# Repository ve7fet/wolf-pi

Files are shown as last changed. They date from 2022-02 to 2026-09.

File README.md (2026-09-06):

# wolf-pi

## What is it?
A carrier board for the NanoPi Duo 2 supporting Direwolf and other amateur radio applications. 
See http://wiki.friendlyarm.com/wiki/index.php/NanoPi_Duo2 for details on the NanoPi Duo 2. Schematics of the NanoPi Duo 2 and it's 
factory carrier board schematic are in the [docs](./docs) folder.

The NanoPi Duo 2 has a built-in sound card (ADC/DAC), GPIO, WiFi, and Ethernet, making it an attractive product for integration.

This device allows you to use a NanoPi Duo 2 with the Direwolf Project. See https://packet-radio.net/direwolf/

## Implementation
In this application, we wire out the Ethernet (following the design used on the NanoPi IoT carrier board), as that is often preferred 
in a stand-alone application, for connection to a LAN.

The GPIO is used with the built-in functions in Direwolf for /PTT and software indication of Carrier Detect.

A 555-based (selectable) time-out-timer is employed, to prevent a locked-up transmitter or software from holding up the radio channel
with dead carrier. This circuit is based on the one recommended in the Direwolf documentation.

For telemetry applications, support for the ADS1115 ADC converter is included. This is accomplished by using a commonly available 
breakout board from Sparkfun/Adafruit/Universal Solder. The header pins for the breakout solder directly on to the carrier.

Non-populated resistor positions are provided for build-your-own voltage dividers for making single-ended ADC measurements (battery voltages, door switches, etc.).

JP2 is provided to facilitate easy measurement of the battery voltage on ADC AN0.

Support for Dallas 1-wire sensors is provided, with pads available to install a DS18B20 on-board, if desired. Note that the onboard DS18B20 will be measuring the temperature inside the enclosure...

ADC and 1-Wire are wired out to a header connector that is external to the case, for external connections.

The DB9 connector is wired to be compatible with Kantronics KPC3+ cables. Additional solder jumpers are provided to modify some of those pin functions for custom applications.

Additional GPIO (buffered) outputs are also added for future use.

Support for hardware COS (DCD) is provided for future applications.

Ferrite beads are used to reduce RFI/EMI.

The board is designed to be installed in a Hammond 1455K1201 case. Actually, it will fit the 1455J1201 (which is thinner). The -1202 version is less expensive (plastic end panels, vs aluminum ones), if you are going to be replacing the end panels with laser cut ones. End plates are still to be designed.

Alternatively, an enclosure has been designed in FreeCad, with the .stl [files available](./enclosure). Confirmed working for the v1.2 board, printed in PLA. Uses #4-40 hardware.

## Usage
The easiest way to get going is to install an [Armbian](https://armbian.com) image, using their imager.

As of 2026/09/03, it was installing:

*v26.11 rolling for NanoPi Duo2 running Armbian Linux 6.18.48-current-sunxi*

### Boot Configuration Changes
In order to utilize all the features of the implementation, additional configuration of the Armbian environment is required.

The following changes are needed to `/boot/armbianEnv.txt` in order to enable the sound card (codec), 1-wire, and i2c (for the ADS1115).

```
overlays=analog-codec i2c0 usbhost0 usbhost2 usbhost3 w1-gpio
param_w1_pin=PA13
param_w1_pin_int_pullup=0
```

### 1-Wire
With the changes to `/boot/armbianEnv.txt`, the 1-wire subsystem will be available in `/sys/bus/w1/devices`.

If the onboard sensor is installed, it should enumerate with a `28-` prefix.

Follow any of the many sources on the Internet for how to utilize it from there.

### ADC via i2c
With the changes to `/boot/armbianEnv.txt`, the ADS1115 daughter board should be detected. 

Install the i2c tools:

```
sudo apt install i2c-tools -y
```

Make sure the bus is there:

```
ve7fet@nanopiduo2:~$ ls /dev/i2c*
/dev/i2c-0
```

Make sure we can see the ADC at address 0x48:

```
ve7fet@nanopiduo2:~$ sudo i2cdetect -y 0
     0  1  2  3  4  5  6  7  8  9  a  b  c  d  e  f
00:                         -- -- -- -- -- -- -- --
10: -- -- -- -- -- -- -- -- -- -- -- -- -- -- -- --
20: -- -- -- -- -- -- -- -- -- -- -- -- -- -- -- --
30: -- -- -- -- -- -- -- -- -- -- -- -- -- -- -- --
40: -- -- -- -- -- -- -- -- 48 -- -- -- -- -- -- --
50: -- -- -- -- -- -- -- -- -- -- -- -- -- -- -- --
60: -- -- -- -- -- -- -- -- -- -- -- -- -- -- -- --
70: -- -- -- -- -- -- -- --
```

Unfortunately, the Armbian kernel doesn't have the driver compiled into it in order to use userspace tools. So, that means one will have to access it directly via i2c.

With a little massaging, the library from https://github.com/sanjuruk/ADS1X15_TLA2024_Linux is capable of accessing the ADC.

Note that the value returned by the "single ended" utility is the ADC count. In order to convert it back to a voltage, you'd need to do something like:

```
#include <cstdio>
#include <unistd.h>
#include "ADS1X15_TLA2024.h"

ADS1115 ads;  /* Use this for the 16-bit version */
// ADS1015 ads;     /* Use this for the 12-bit version */
// TLA2024 ads;

int DEBUG = 1;
float AIN0vout, AIN1vout, AIN2vout, AIN3vout;
float AIN0cal, AIN1cal, AIN2cal, AIN3cal;
float PGA = 4.096; /* PGA is defined by GAIN setting */

// AIN0 Resistors
float R5 = 10000; // 10k ohms
float R6 = 3000;  // 3k ohms
// AIN1 Resistors
float R7 = 1; // dummy, so we don't divide by 0
float R8 = 1; // dummy, so we don't divide by 0
// AIN2 Resistors
float R9 = 1000; // 1kohm
float R10 = 3740; // 3.74kohm
// AIN3 Resistors
float R12 = 1;
float R13 = 1;

// AIN0 Max Input Voltage
//
// VINmax = (VDD + 0.3) x ((R5 + R6)/R6)
// VINmax = (3.6) x ((13000)/3000)
// VINmax = 15.6VDC
//
// AIN2 Max Input Voltage
//
// VINmax = (VDD + 0.3) x ((R9 + R10)/R10)
// VINmax = (3.6) x ((4740)/3740)
// VINmax = 4.56VDC

int main()
{
    int16_t adc[4];
    int8_t i;

    if (DEBUG) {
        printf("Getting single-ended readings from AIN0..3\n");
        printf("ADC Range: +/- 4.096V (1 bit = 2mV/ADS1015, 0.125mV/ADS1115)\n");
        printf("ADC Max Input: VDD + 0.3 = 3.6VDC\n\n");
    }

  // The ADC input range (or gain) can be changed via the following
  // functions, but be careful never to exceed VDD +0.3V max, or to
  // exceed the upper and lower limits if you adjust the input range!
  // Setting these values incorrectly may destroy your ADC!
  //                                                                ADS1015  ADS1115
  //                                                                -------  -------
  // ads.setGain(GAIN_TWOTHIRDS);  // 2/3x gain +/- 6.144V  1 bit = 3mV      0.1875mV (default)
  //
  // We're using VDD = 3.3V, so we will use GAIN_ONE to get the most resolution, being
  // careful to choose our voltage divider resistors!
    ads.setGain(GAIN_ONE);        // 1x gain   +/- 4.096V  1 bit = 2mV      0.125mV
  // ads.setGain(GAIN_TWO);        // 2x gain   +/- 2.048V  1 bit = 1mV      0.0625mV
  // ads.setGain(GAIN_FOUR);       // 4x gain   +/- 1.024V  1 bit = 0.5mV    0.03125mV
  // ads.setGain(GAIN_EIGHT);      // 8x gain   +/- 0.512V  1 bit = 0.25mV   0.015625mV
  // ads.setGain(GAIN_SIXTEEN);    // 16x gain  +/- 0.256V  1 bit = 0.125mV  0.0078125mV

    for (i = 0; i < 4; i++) {
        adc[i] = ads.readADC_SingleEnded(i);
        if (DEBUG) {
            printf("AIN%i: %d\n", i, adc[i]);
        }
    }

    /* Calculate output voltage for AIN0. */
    AIN0vout = (adc[0]*(PGA/32767))*((R5+R6)/R6);
    printf("AIN0vout = %.2f\n", AIN0vout);

    /* Calculate output voltage for AIN1. */
    AIN1vout = (adc[1]*(PGA/32767))*((R7+R8)/R8);
    printf("AIN1vout = %.2f\n", AIN1vout);

    /* Calculate output voltage for AIN2. */
    AIN2vout = (adc[2]*(PGA/32767))*((R9+R10)/R10);
    printf("AIN2vout = %.2f\n", AIN2vout);

    /* Calculate output voltage for AIN3. */
    AIN3vout = (adc[3]*(PGA/32767))*((R12+R13)/R13);
    printf("AIN3vout = %.2f\n", AIN3vout);
```
See https://github.com/ve7fet/wolfpiADC for the full library.

### Sound Card
You can use `alsamixer` to set the audio levels. Use `sudo alsactl store` to save settings in `/var/lib/alsa/asound.state` (*remember to backup this file*).

If you run Direwolf out of the box, it will likely complain:

```
Audio input device 0 error code -5: Input/output error
```

That is because there is no capture device selected. You can either run this:

```
#mic1 CAPTURE switch (on/off) - this will let you use the microphone
/usr/bin/amixer -c 0 cset numid=18 on
```

Or, load `alsamixer`, and select MIC1 as the capture device.

### GPIO
We use GPIO for the /PTT (signal and LED), and the DCD LED.

Put the following in the `direwolf.conf` for Channel 0 to enable them:

```
MODEM 1200

# Our PTT is on GPIOL11 (Pin 9)
PTT GPIO 363
# Our DCD LED is on GPIOG11 (Pin 11)
DCD GPIO 203
```

Note that this is the deprecated sysfs way of using the GPIOs... but it works, for now.

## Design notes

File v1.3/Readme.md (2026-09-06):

This version makes the following changes from v1.2:

- Fix C14/C20 Silkscreen. 
- Change solder jumpers to open. YOU NEED TO SOLDER THE OPTIONS YOU WANT DURING ASSEMBLY.
- Change TOT jumper to solder type instead of pin header. 
- Change DB9 mounting holes to plated/GND. 
- Move ETH jack outward.
- Move C11, D3, JP6.
- Correct R11/C9/U1 connections for TOT
- Update value of R6 to increase Vmax for AIN0 from 13.2V to 15.6V

This version has NOT been manufactured (yet) to verify operation.

Project/Schematic/Board saved with KiCad V9.04. DRC needs to be re-run, errors/warnings addressed, 
and Gerbers re-exported (existing Gerbers have been removed, as they are no longer valid).

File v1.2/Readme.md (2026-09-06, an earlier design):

This is the initial prototype release.

Prototype boards WERE produced and tested with this release, and did work. 

Known issues:
- C11 obstructs the USB port on the NanoPi
- JP1 should have been a solder jumper, not a physical header
- C14/C20 silkscreens are swapped
- TOT doesn't function. R11 should connect from 3V3 to C9, and U1-6/7 
  should connect to junction of R11/C9 (field change required)
- AN0 max input with R5=10k/R6=3.74k is 13.2VDC. Change R6 to 3.00k 
  for 15.6VDC max.
- Radio MAY transmit for up to TOT value when device is powered on, due 
  to un-initialized GPIO pins

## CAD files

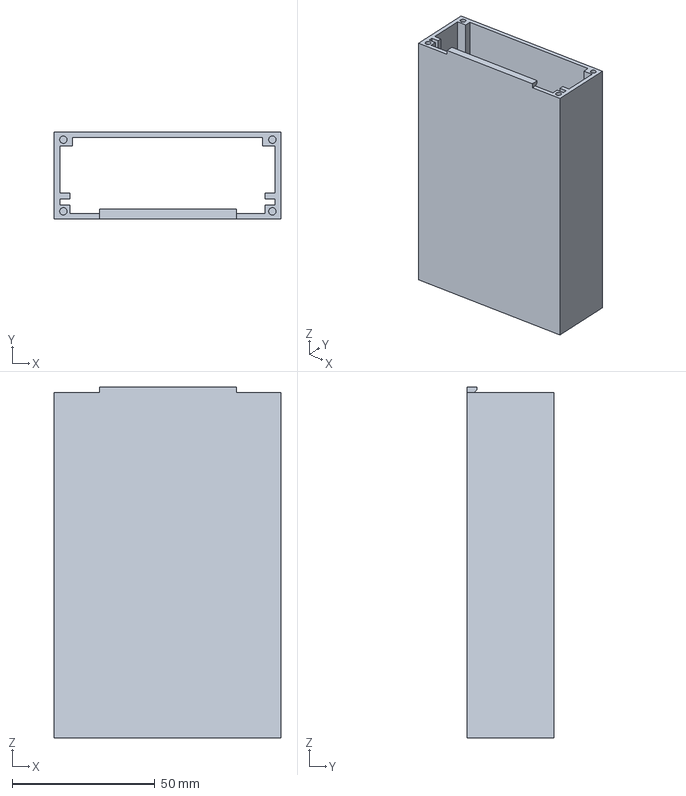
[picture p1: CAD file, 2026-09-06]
enclosure/WolfPiBox_v1.2_121mmdeep.FCStd
79.5 x 30.6 x 123.0 mm

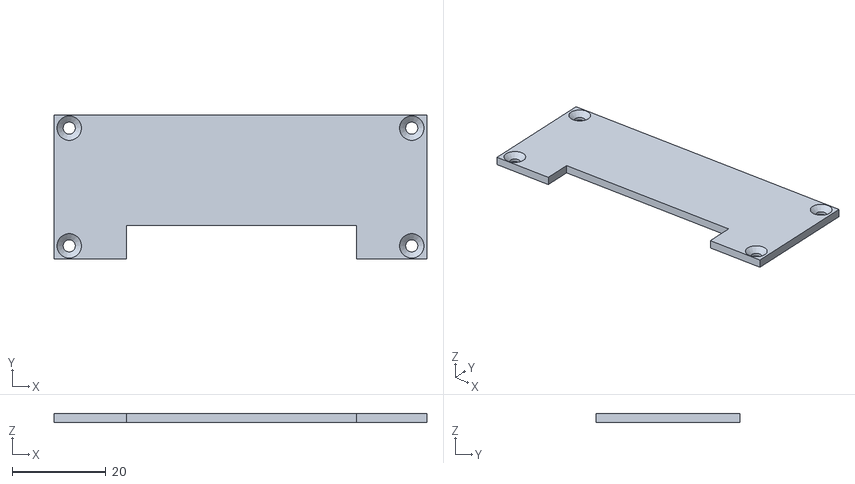
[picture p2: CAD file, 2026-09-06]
enclosure/WolfPiBox_v1.2_121mmdeep-TopLid.stl
79.5 x 30.6 x 2.00

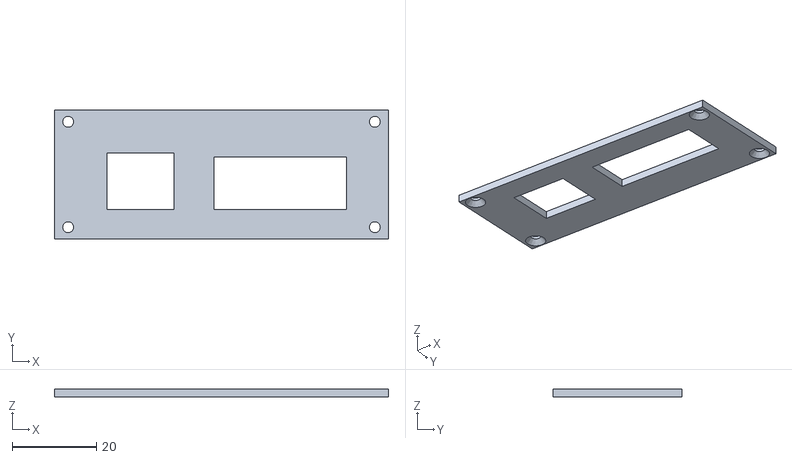
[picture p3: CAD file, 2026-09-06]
enclosure/WolfPiBox_v1.2_121mmdeep-BotLid.stl
79.5 x 30.6 x 2.00

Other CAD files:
enclosure/WolfPiBox_v1.2_121mmdeep-WolfPiCase.stl

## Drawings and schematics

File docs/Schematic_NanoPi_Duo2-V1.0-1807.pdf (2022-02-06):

D | D
C | C
B | B
A | A

# Revision: V1.0 1807 first release

# NanoPi Duo2

Size | Document Number | R e v
Date: | Sheet | o f

Title

NanoPi Duo2

A3

Thursday, September 27, 2018 | 1 | 11

V1.0 1807

Title

Thursday, September 27, 2018 | 1 | 11

Title

Thursday, September 27, 2018 | 1 | 11

D | D
C | C
B | B
A | A

## MicroUSB OTG

## IR-RX

AP6212

## USB3

# POWER

## LINE OUT

## MICIN1

## 2.54mm 16Pin

SD | TF CARD
USB0 | OSC 24M | 24MHz

## IR RX

## EPHY

H3

## MicroUSB

## WIFI

# BLOCK

DDR3 16X1 | DRAMC0

## UART0

## GPIO

I2C0

## SPI1

## 2.54mm 16Pin

SPI Flash | SPI0 | Bluetooth

BLOCK

Thursday, September 27, 2018 | 2 | 11

BLOCK

Thursday, September 27, 2018 | 2 | 11

BLOCK

Thursday, September 27, 2018 | 2 | 11

D | D
C | C
B | B
A | A
SY8089A | SYSTEM 1.2V/2A

# POWER TREE

MicroUSB/Ext-5V | 5V/2A

# VDD_5V_OUT

RT8059 | DRAM

# VCC-IO/RTC/VCC-WIFI/AVCC RT8059

MP2143DJ | VCC-CPUX

1.5V/1A

1.3V/3A

3.3V/1A

# VCC2.8V-CAM

# RT9011-FMPJ6

# VCC1.5V-CAM

RT9011-PGPJ6 | VCC3V-CAM

POWER TREE

Thursday, September 27, 2018 | 3 | 11

POWER TREE

Thursday, September 27, 2018 | 3 | 11

POWER TREE

Thursday, September 27, 2018 | 3 | 11

55

44

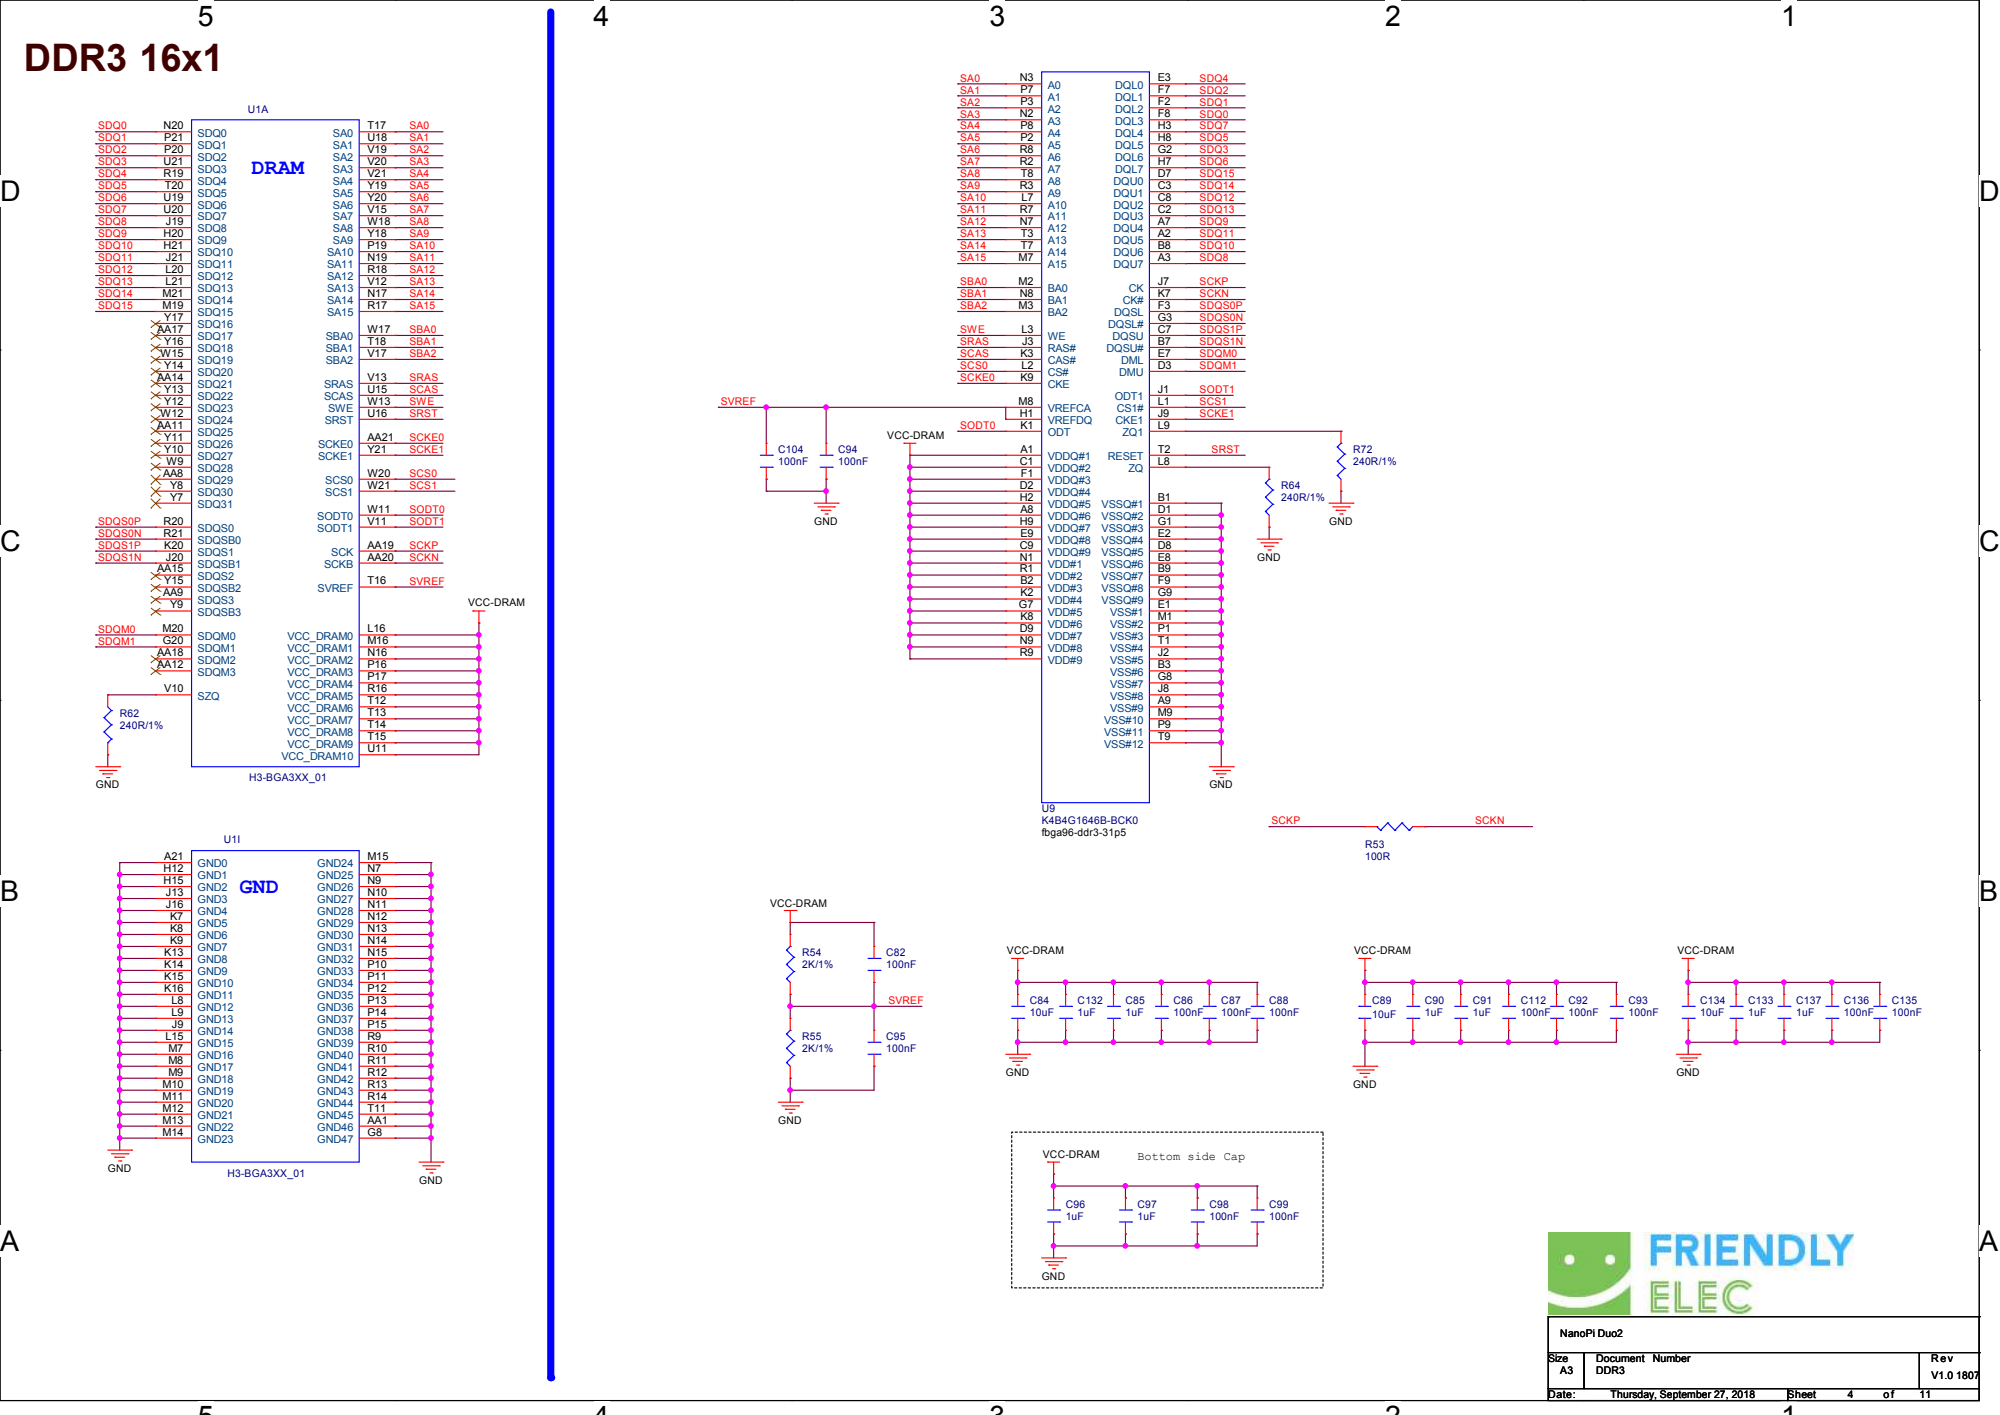
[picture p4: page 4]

D | D

# CPU 01

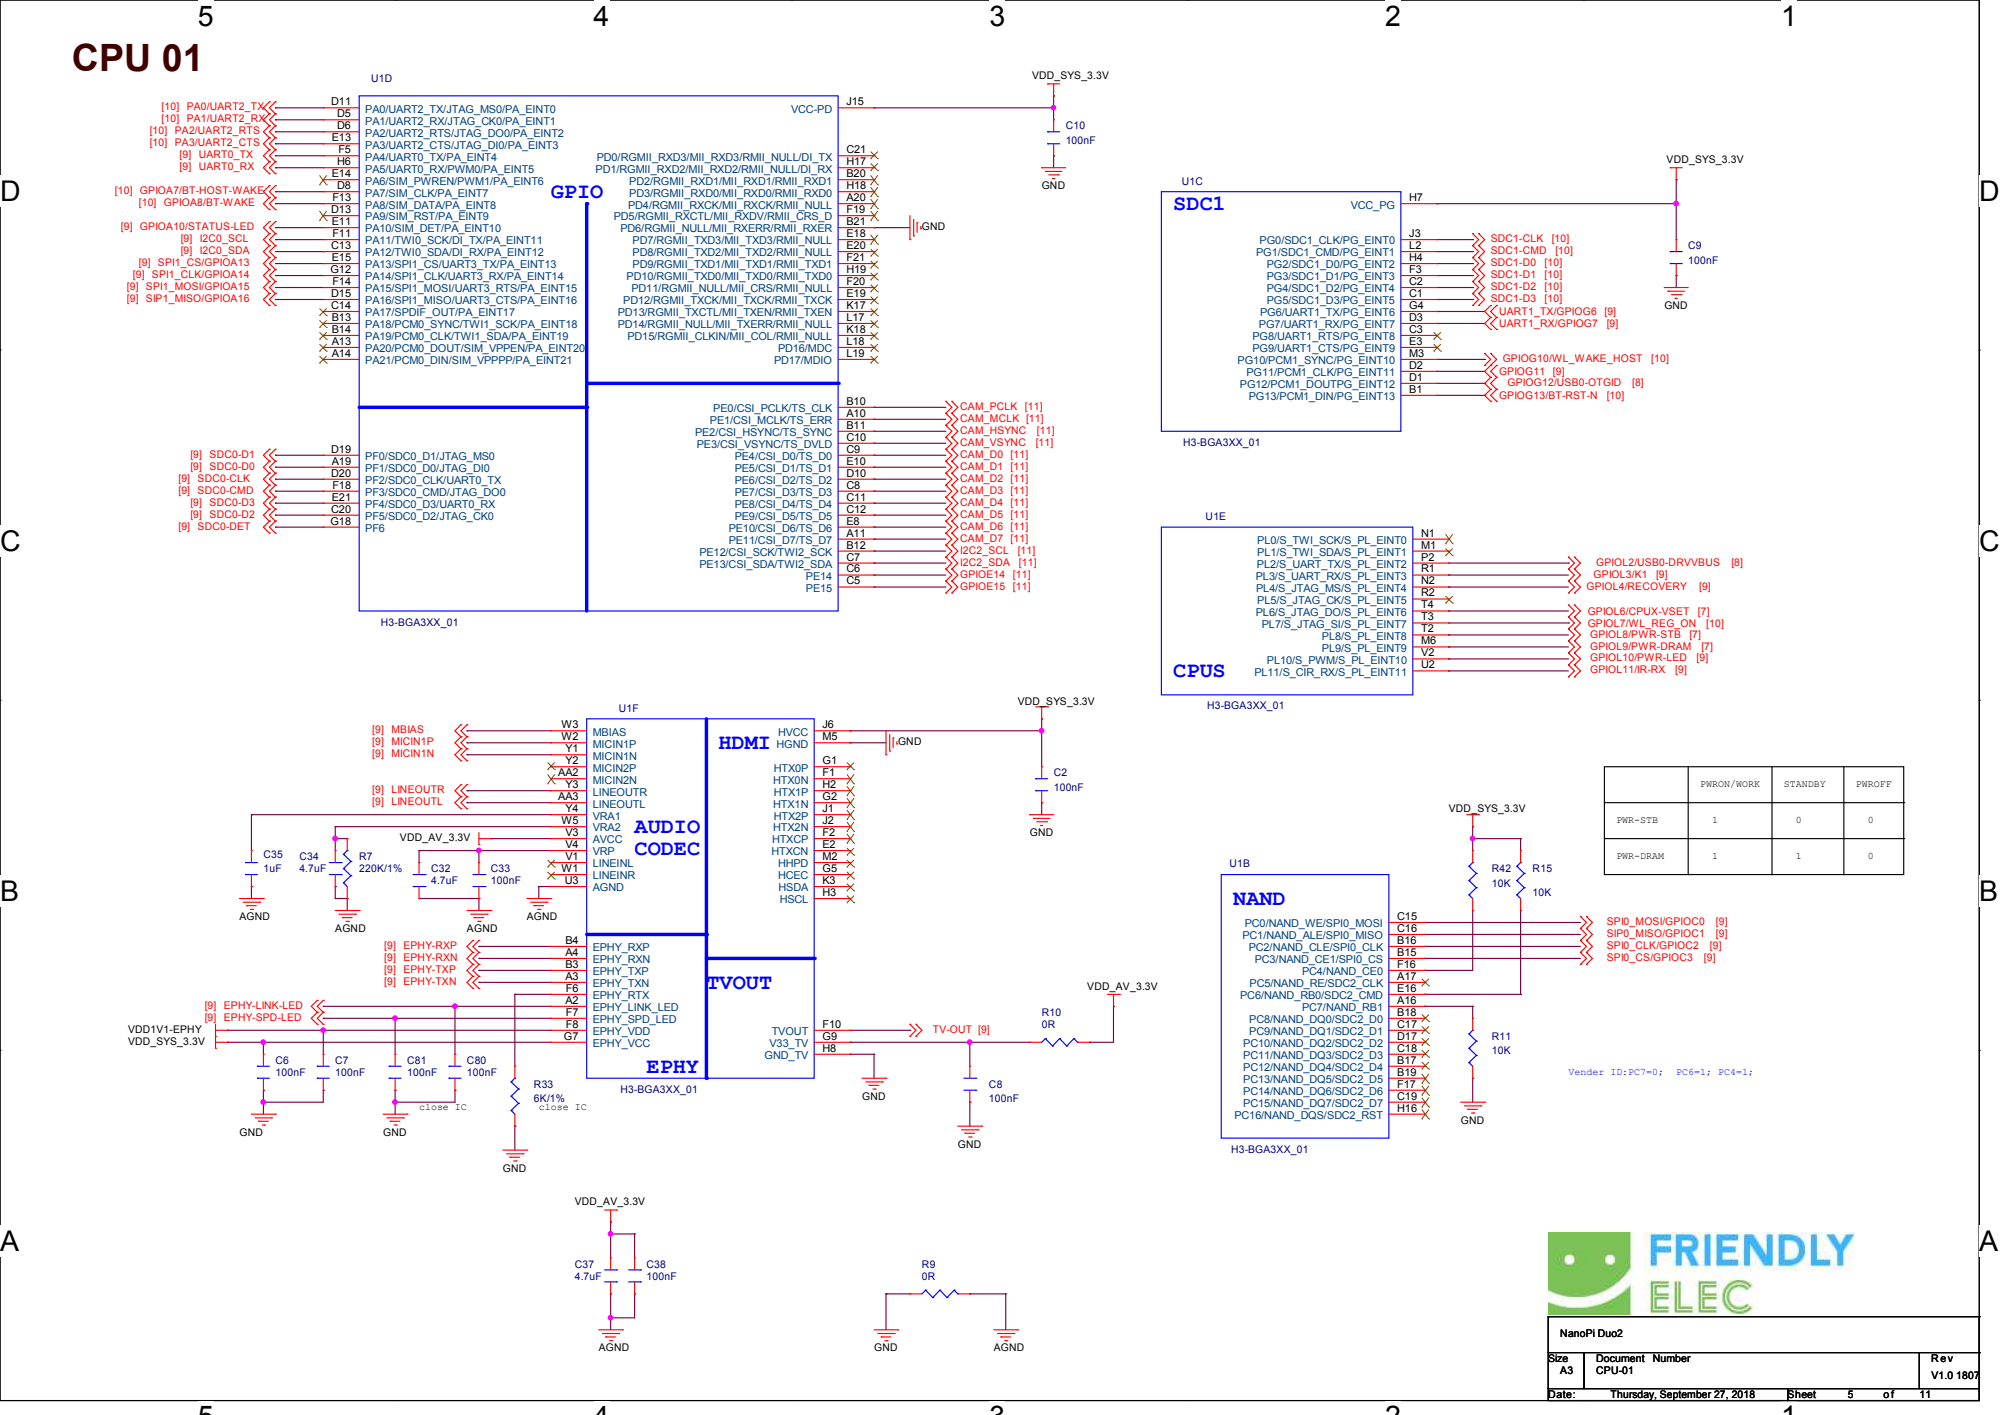
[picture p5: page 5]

D | D

# CPU 02

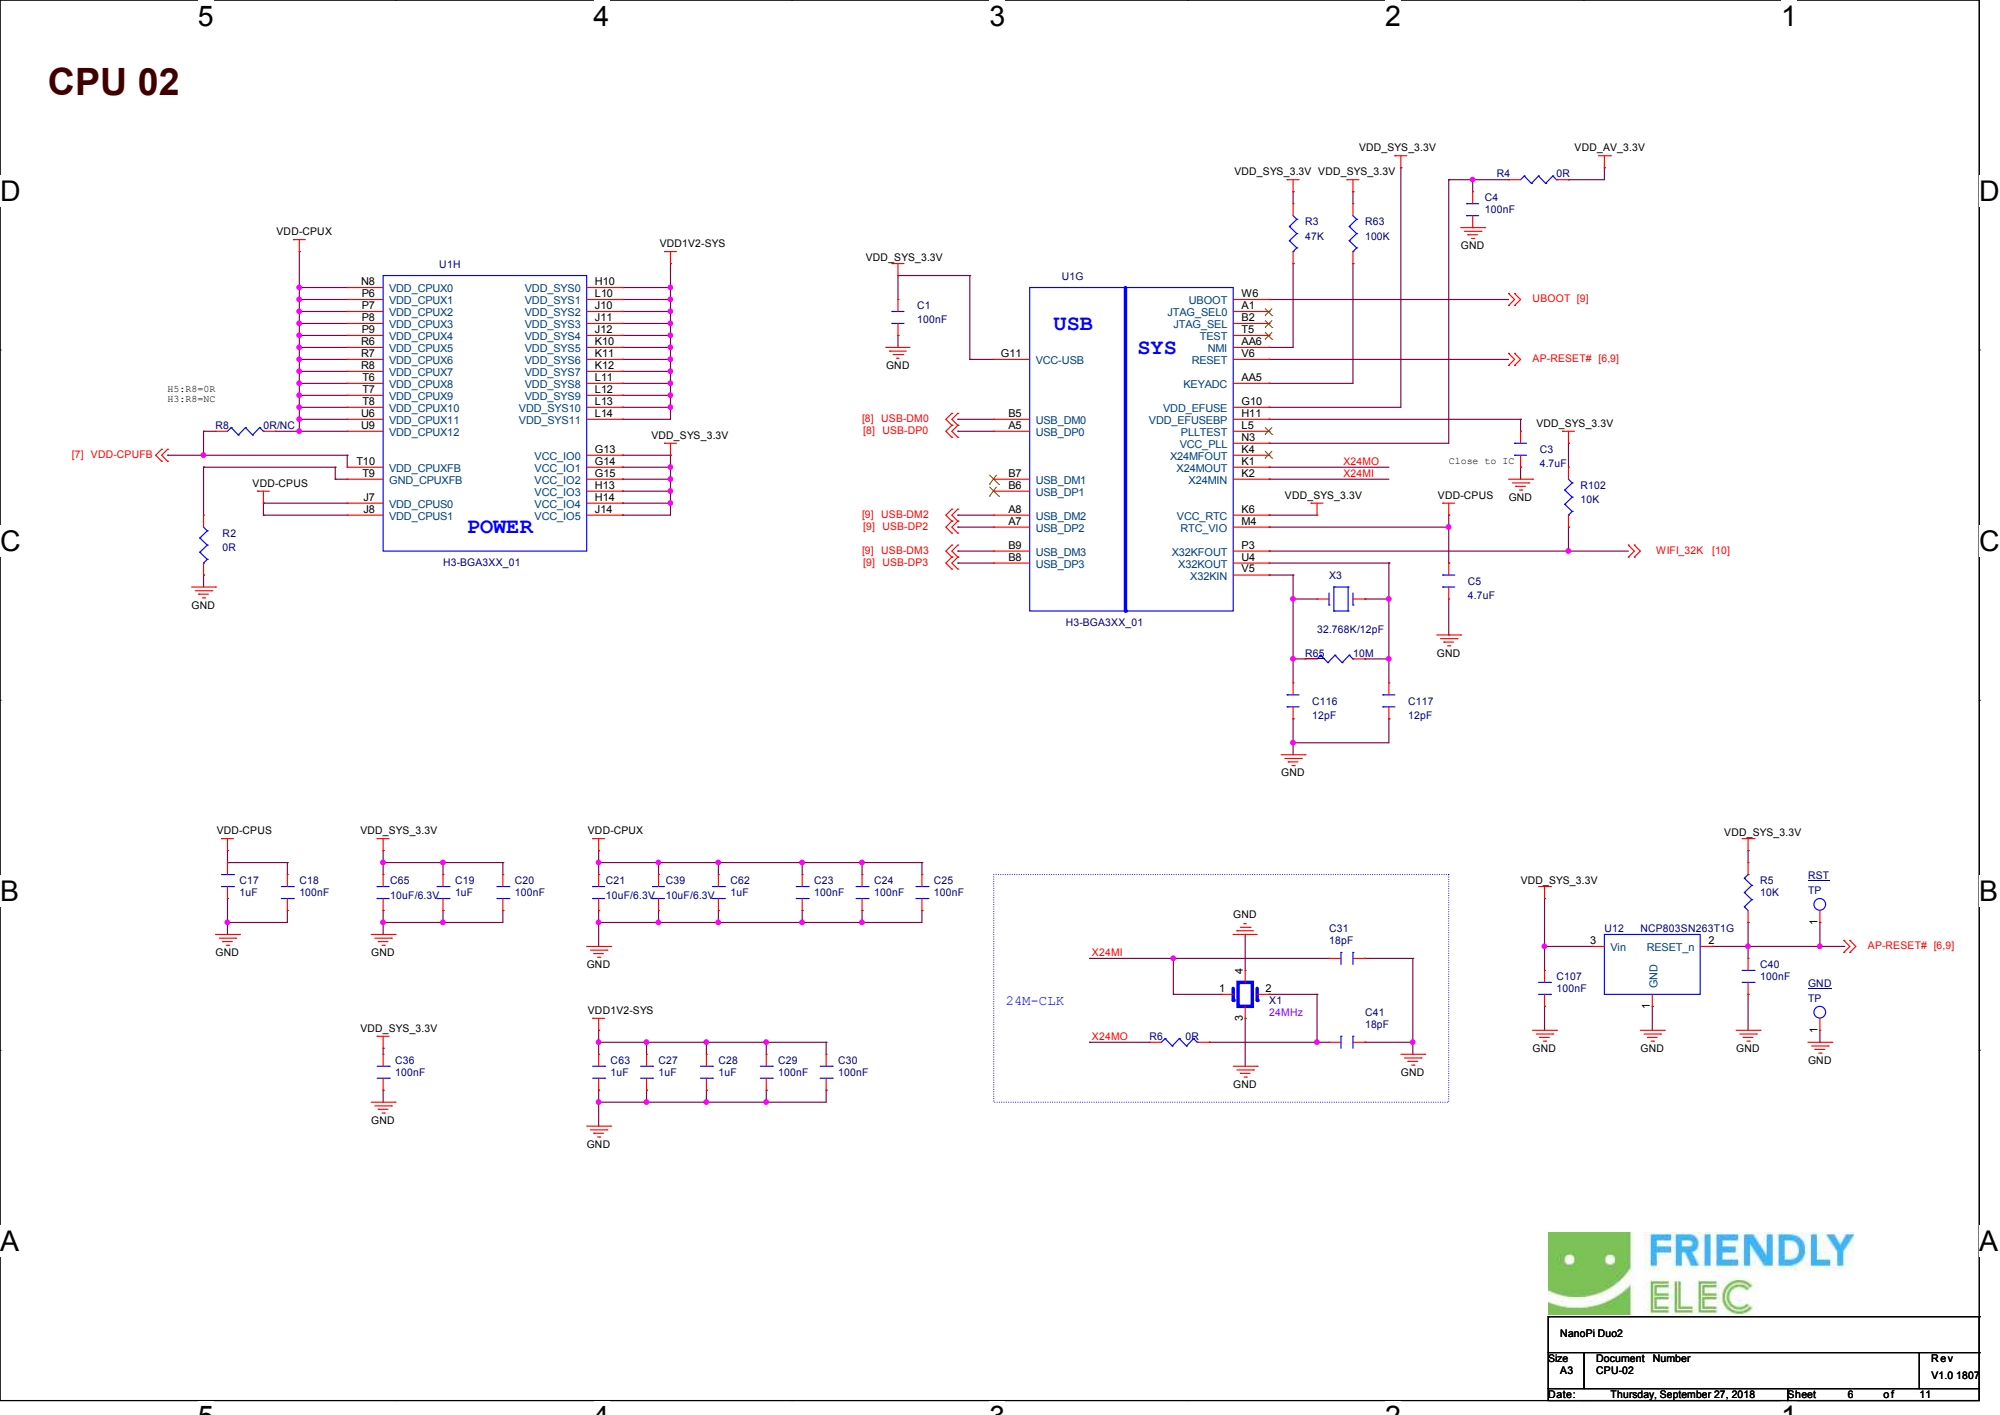
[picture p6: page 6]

D | D

# POWER 01

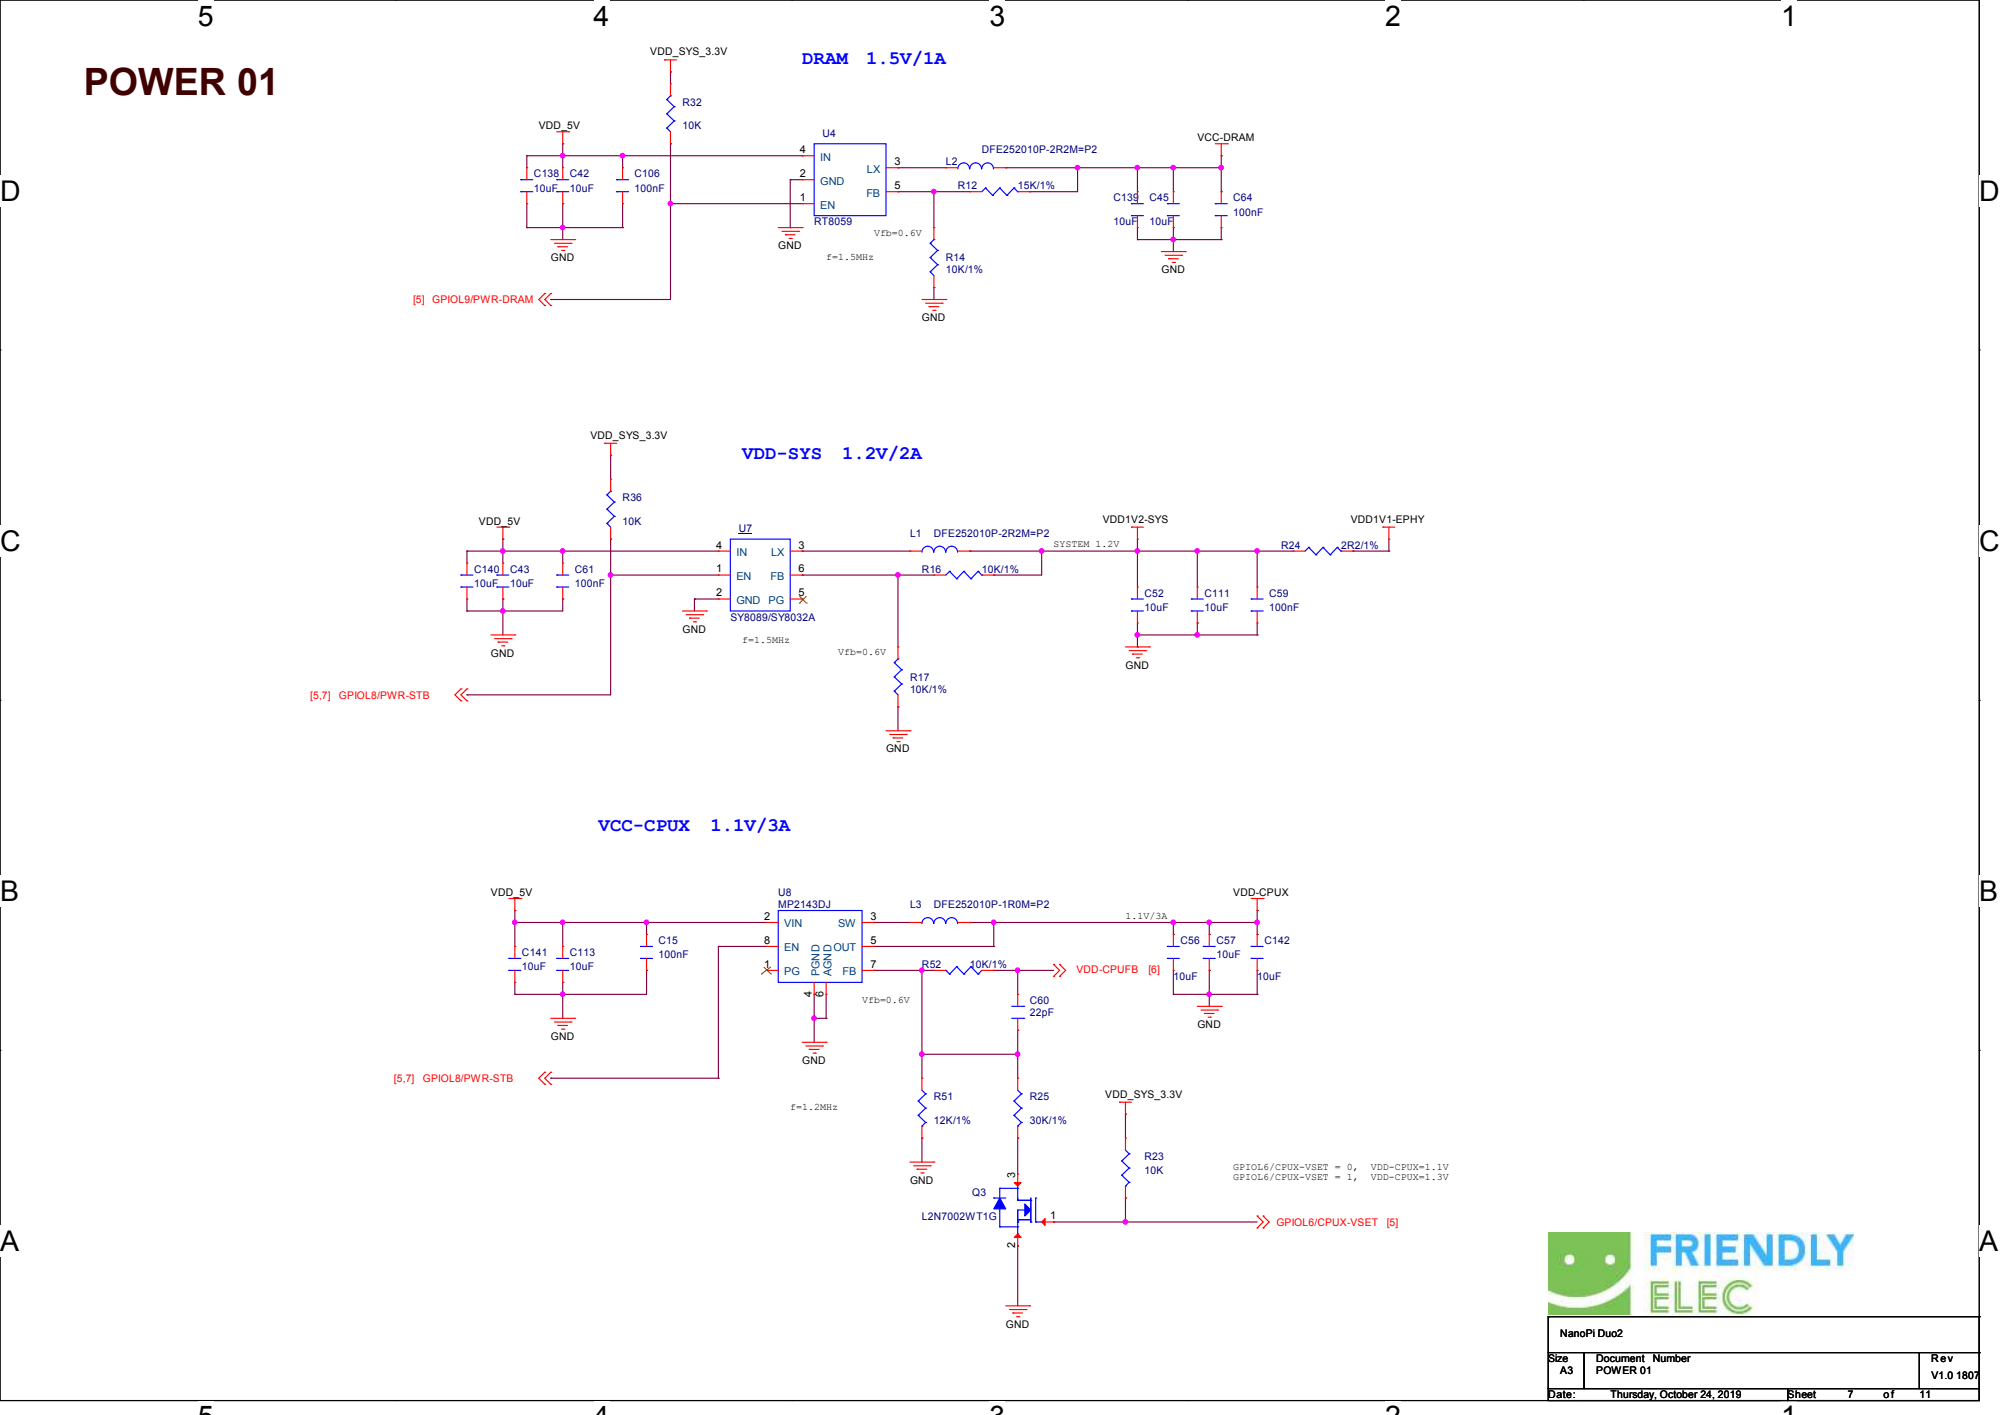
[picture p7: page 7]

D | D

# POWER 02

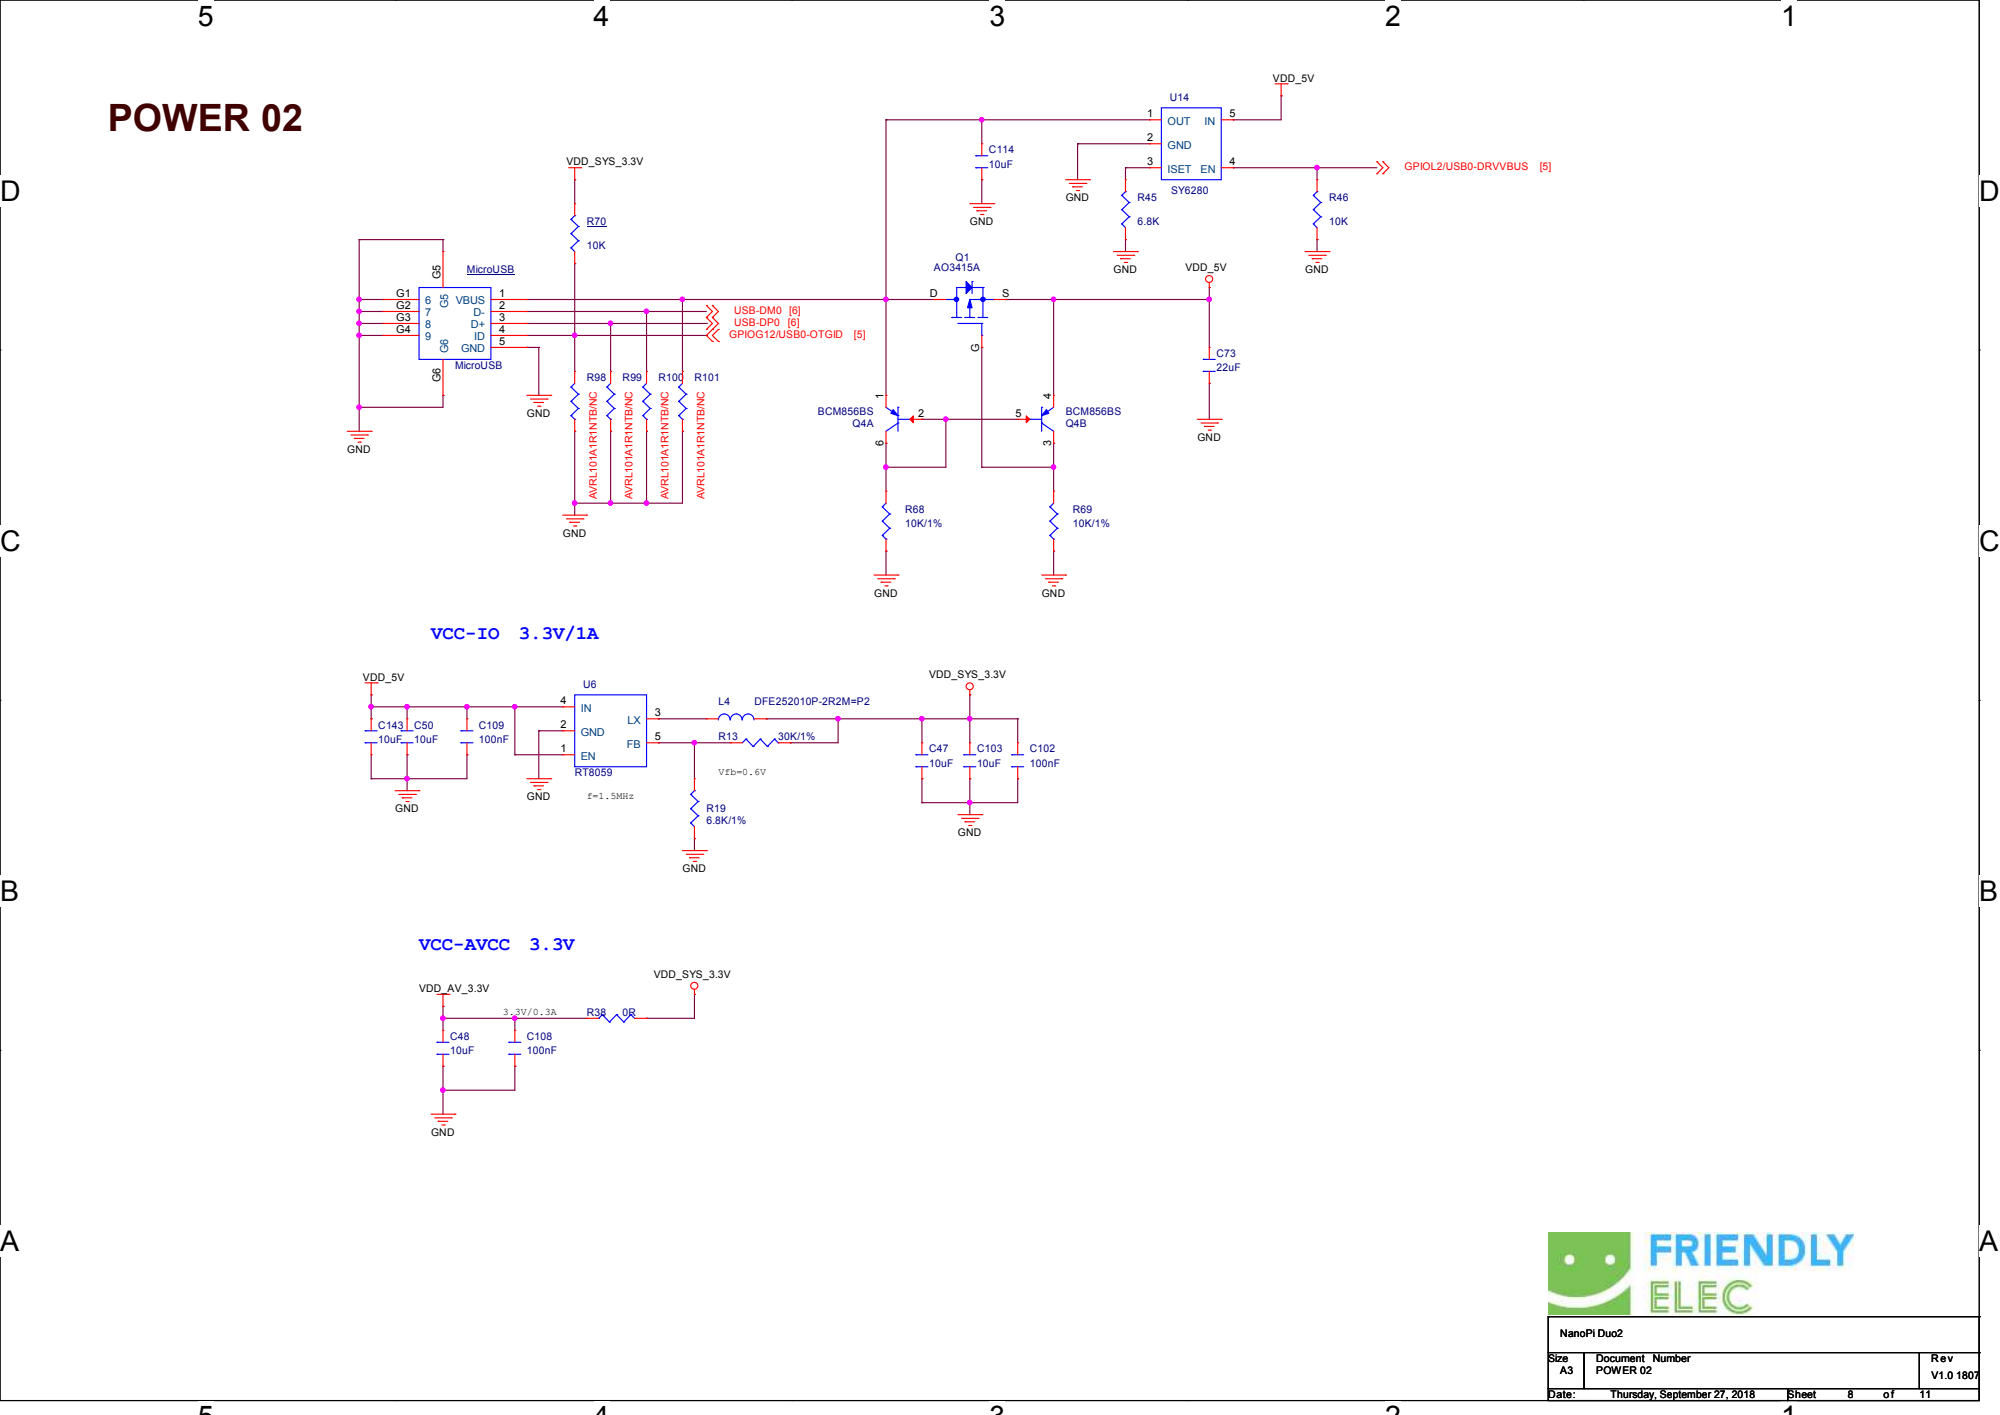
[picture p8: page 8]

D | D

# GPIO,LEDs,TF Card,SPI Flash

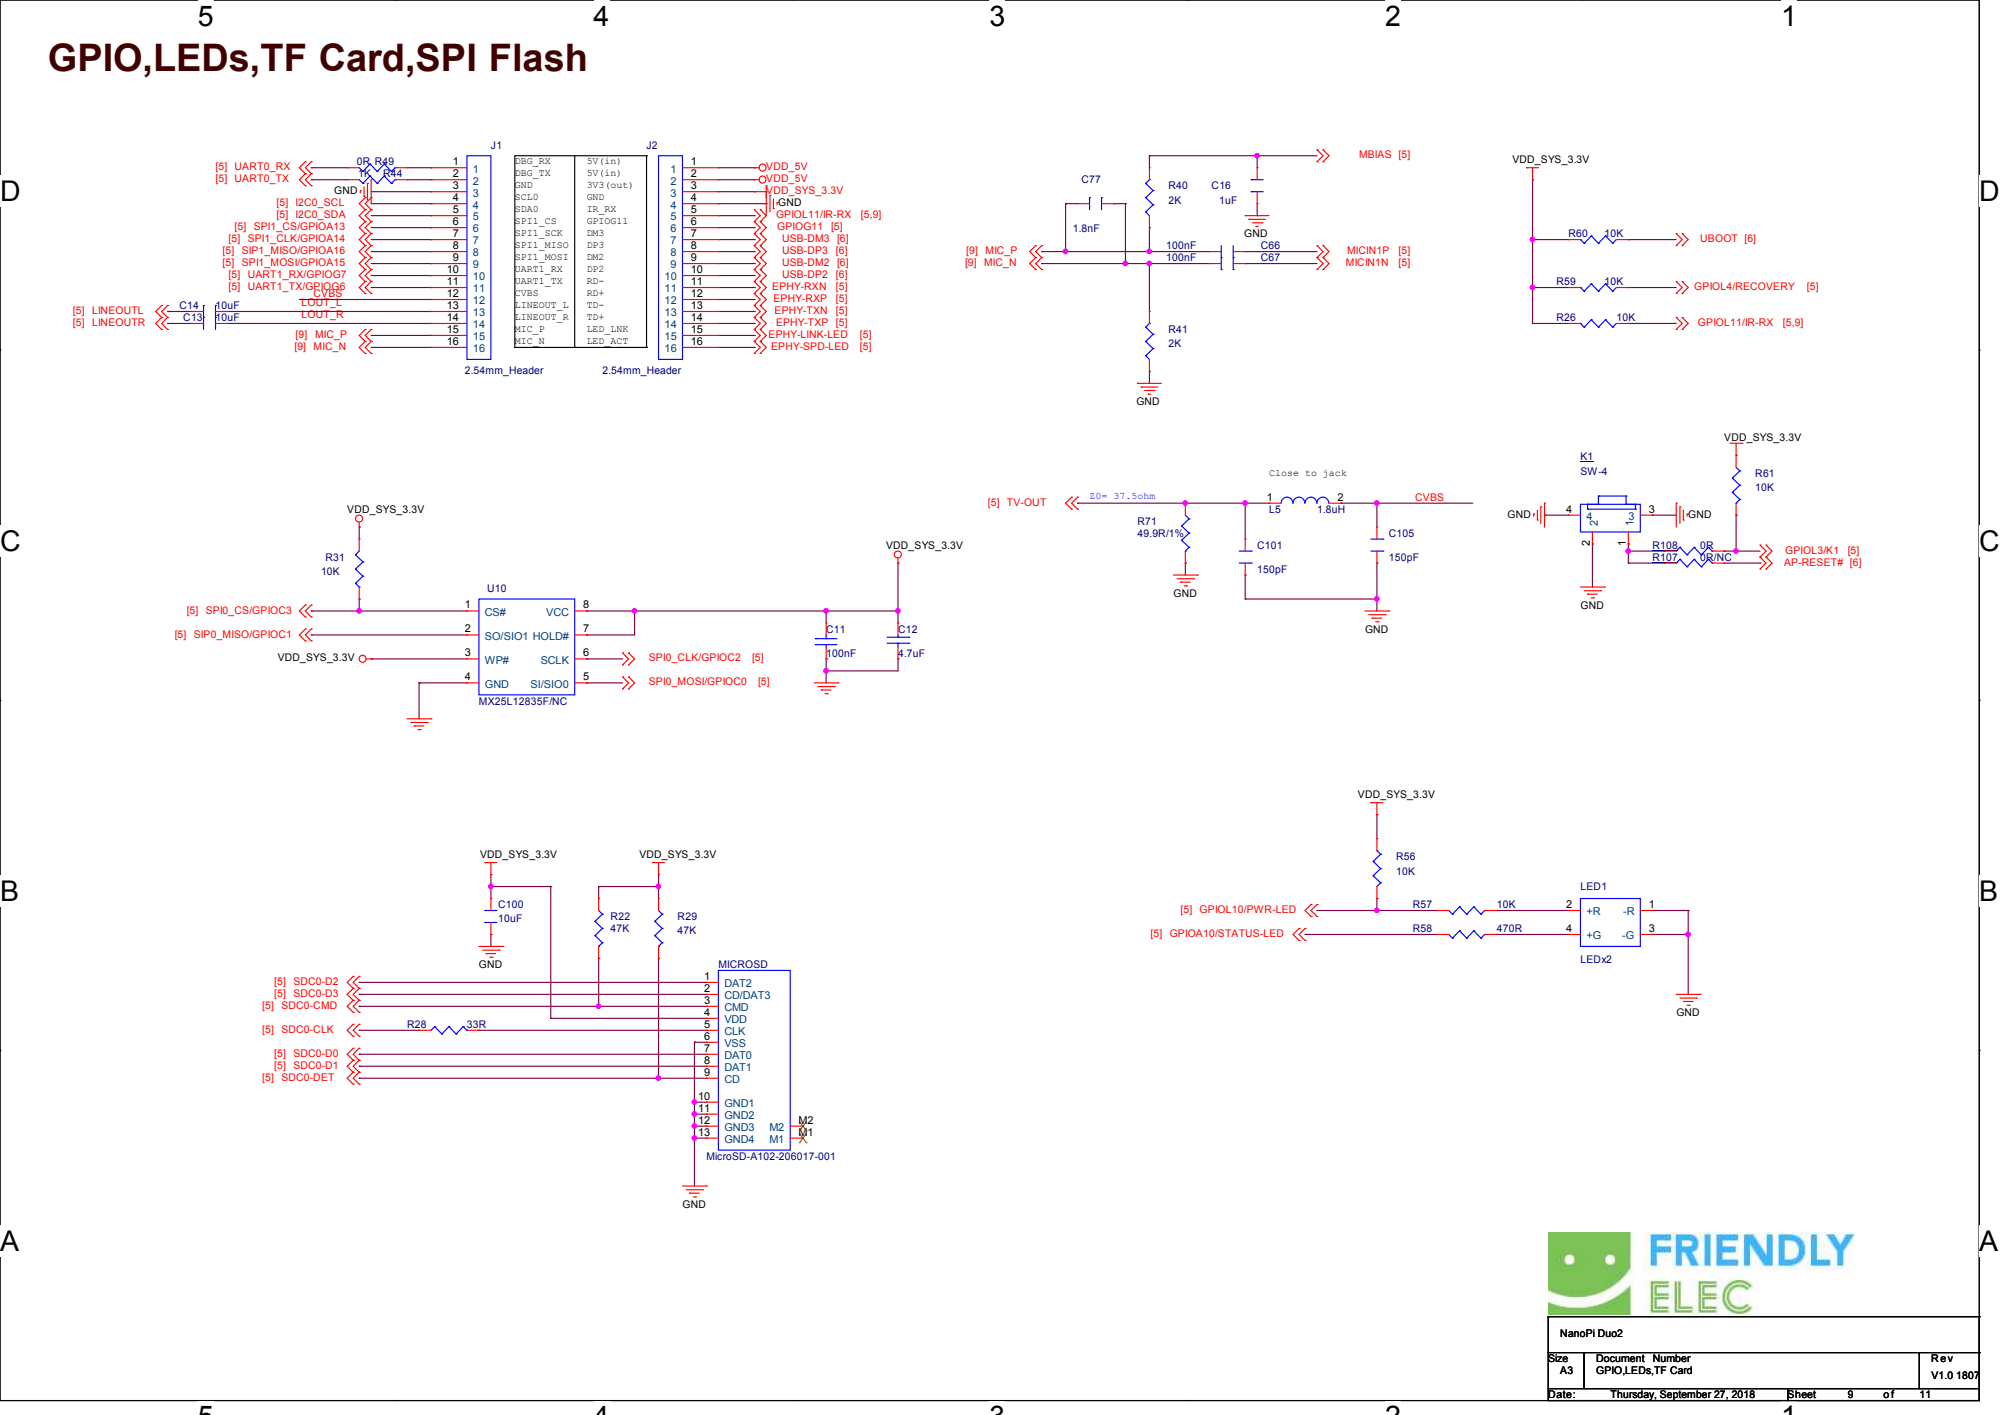
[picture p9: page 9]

GPIO,LEDs,TF Card

D

# WIFI

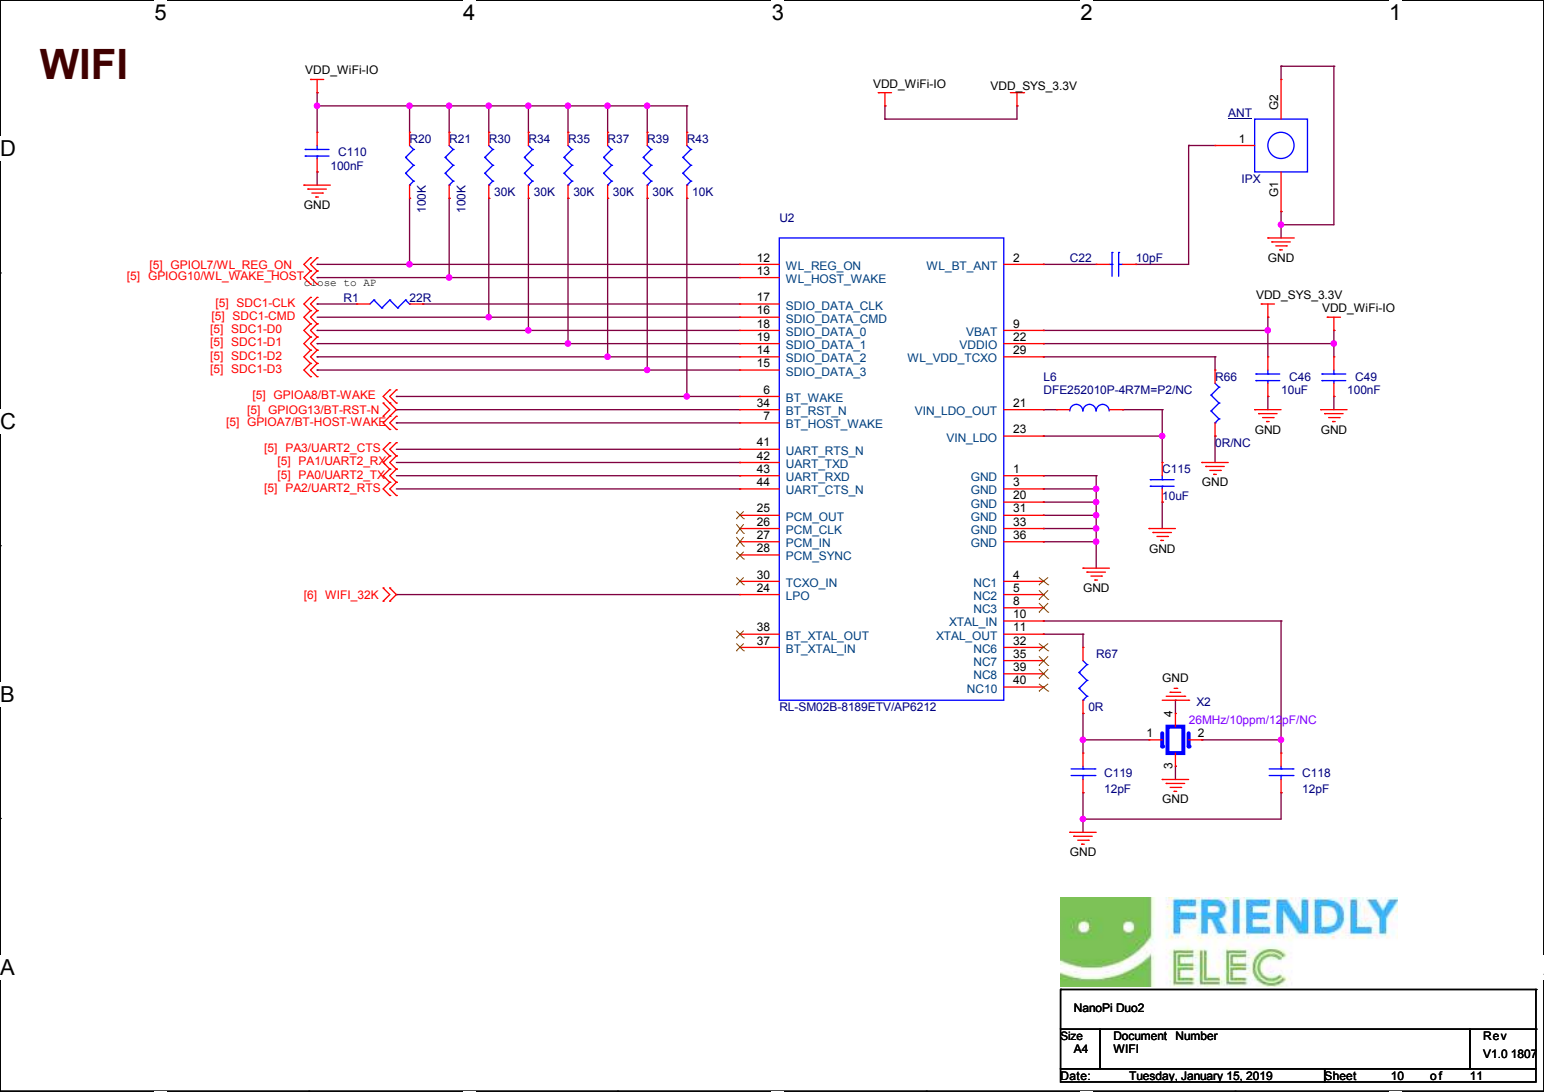
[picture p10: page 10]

D | D

# Camera

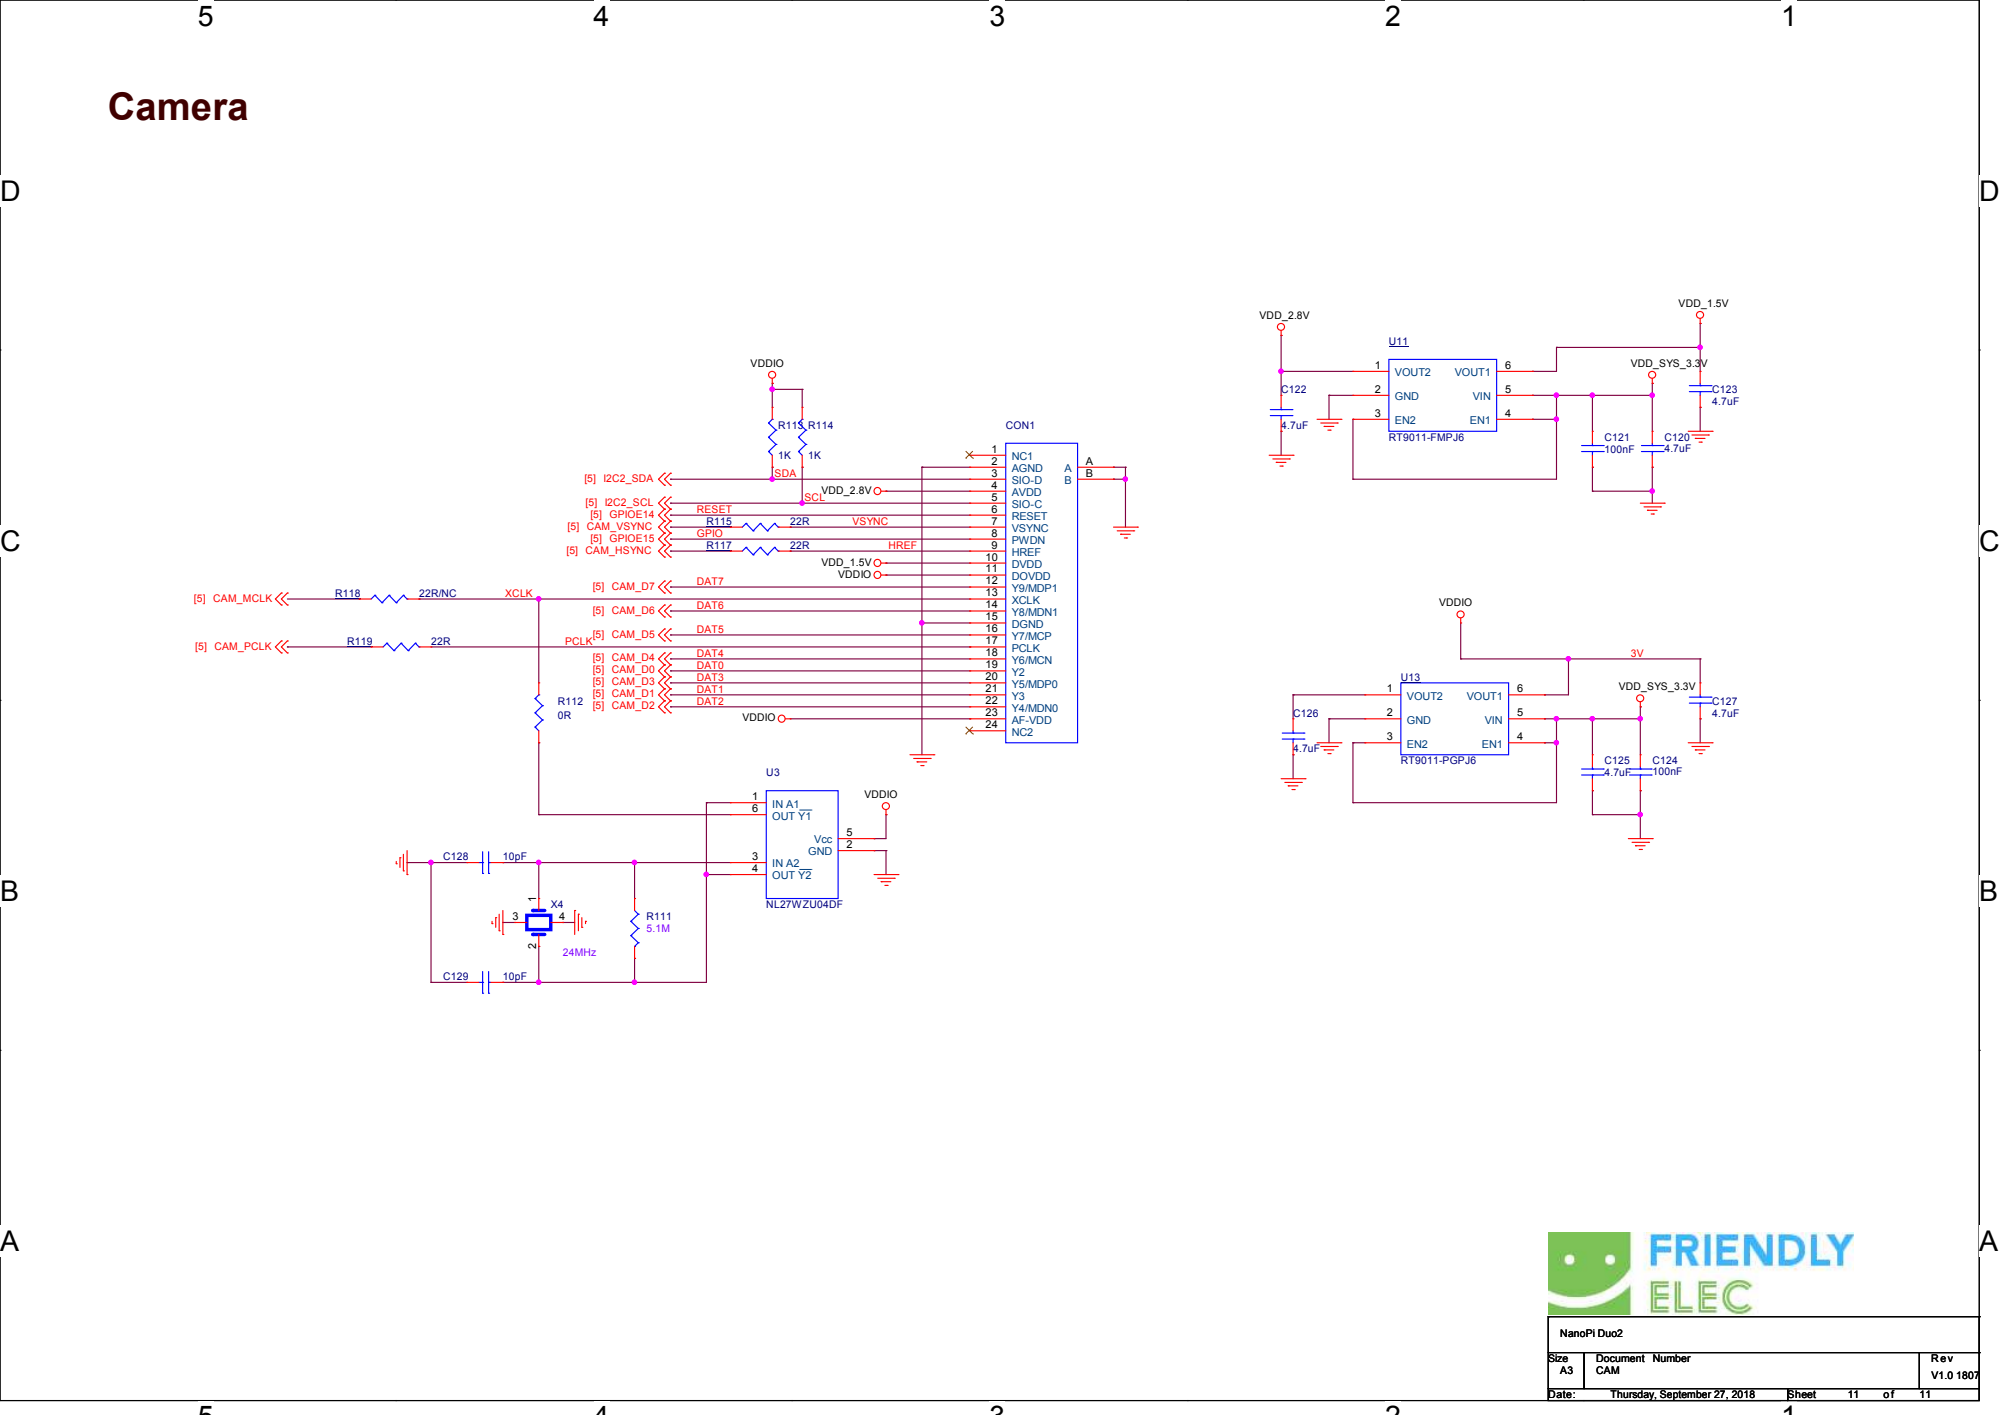
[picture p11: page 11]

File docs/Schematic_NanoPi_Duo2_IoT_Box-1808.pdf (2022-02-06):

5

4

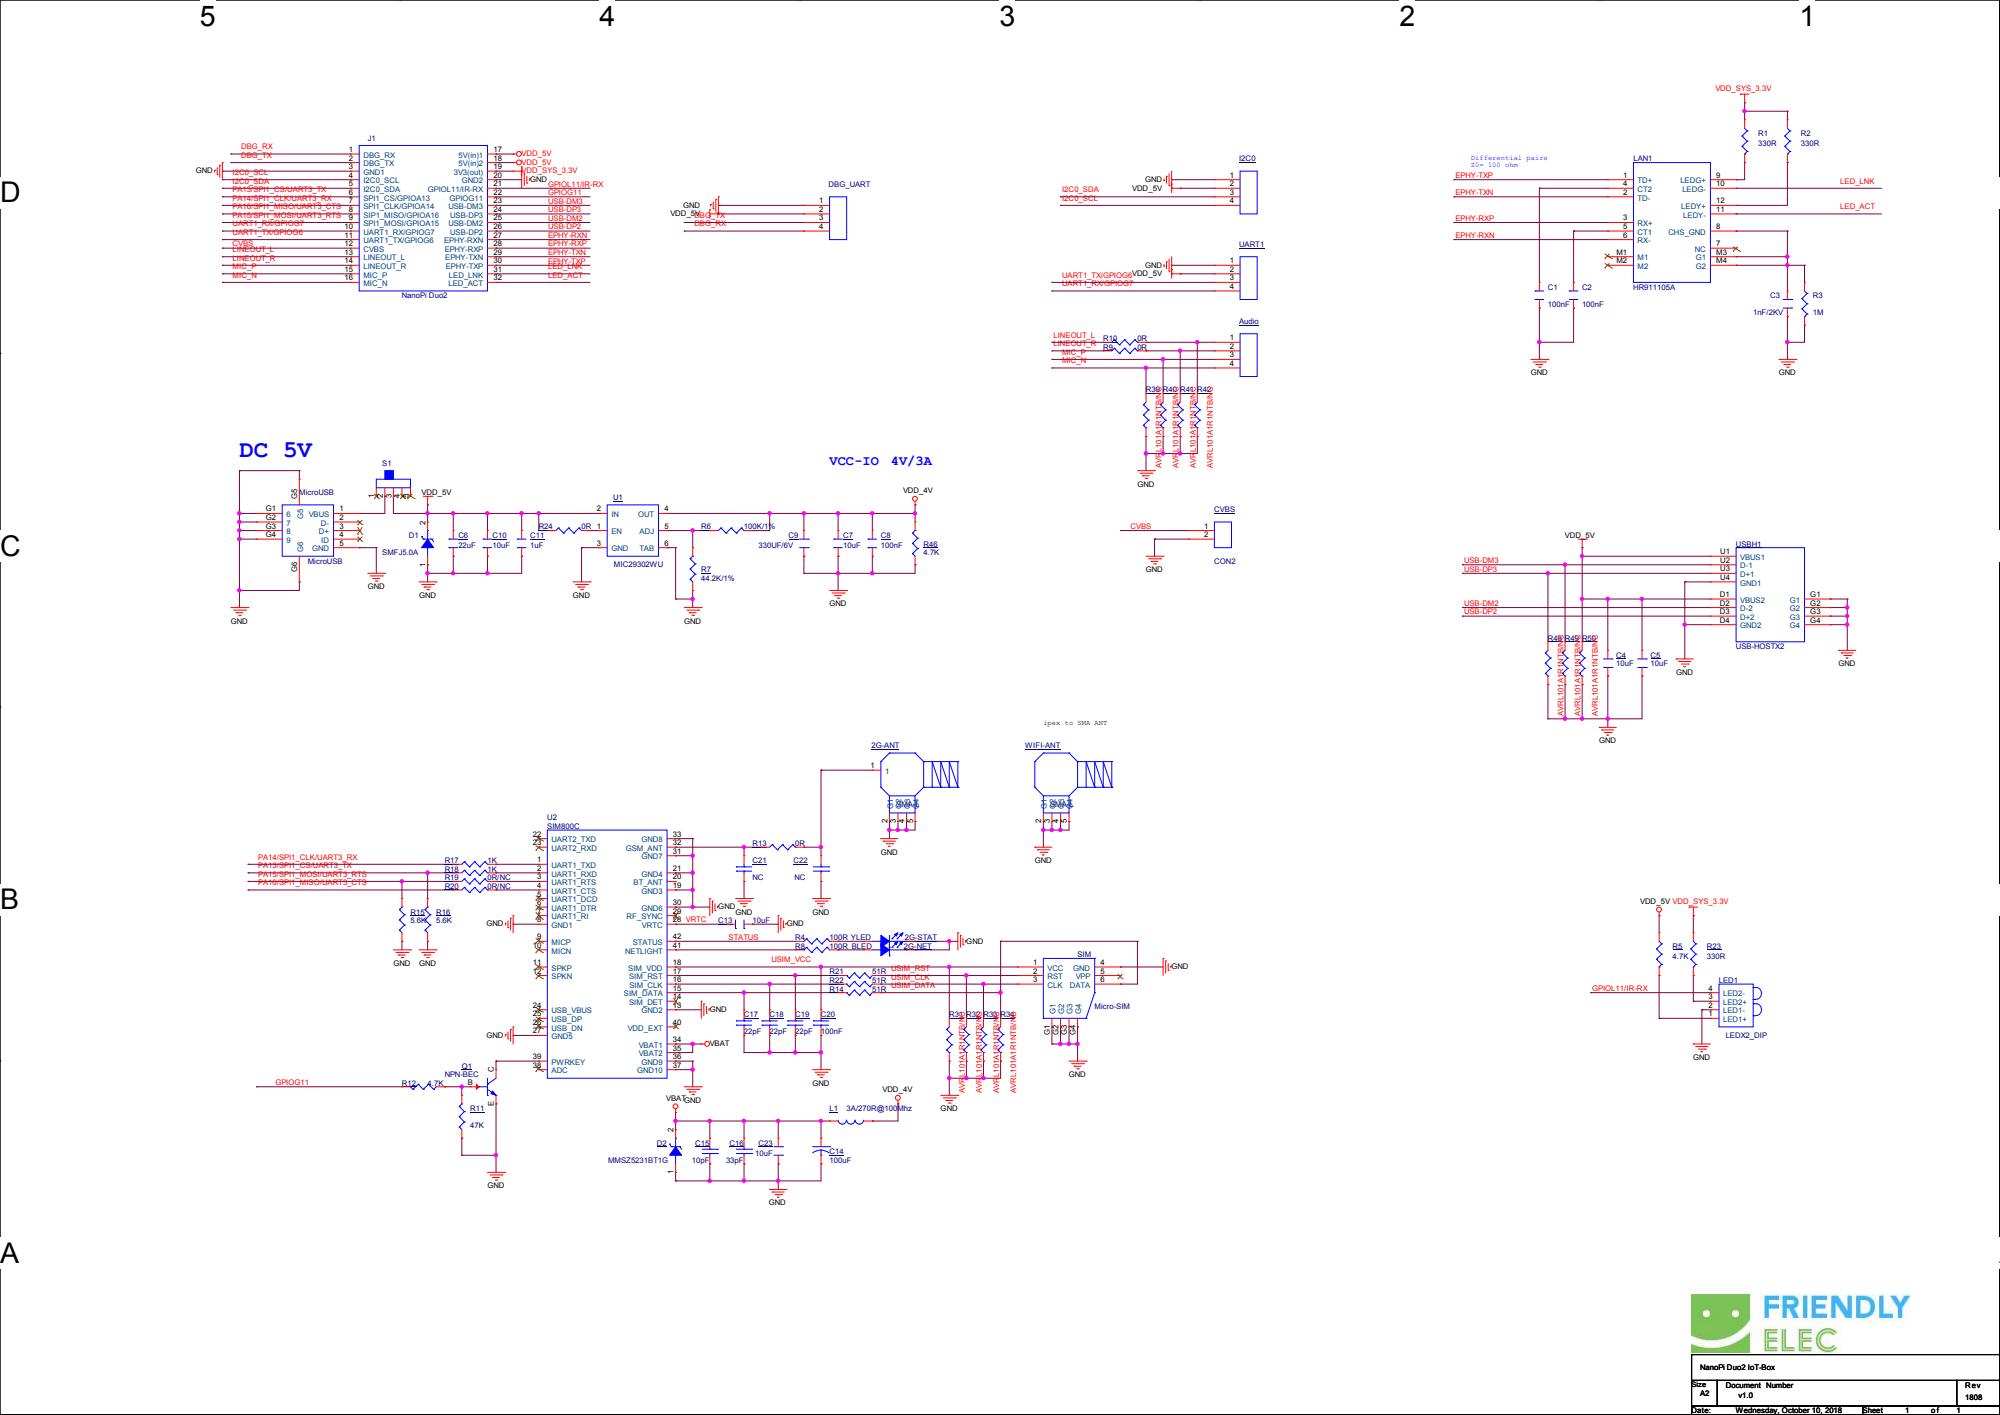
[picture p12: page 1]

ipex to SMA ANT

USIM_RST R21 51R | RST 2

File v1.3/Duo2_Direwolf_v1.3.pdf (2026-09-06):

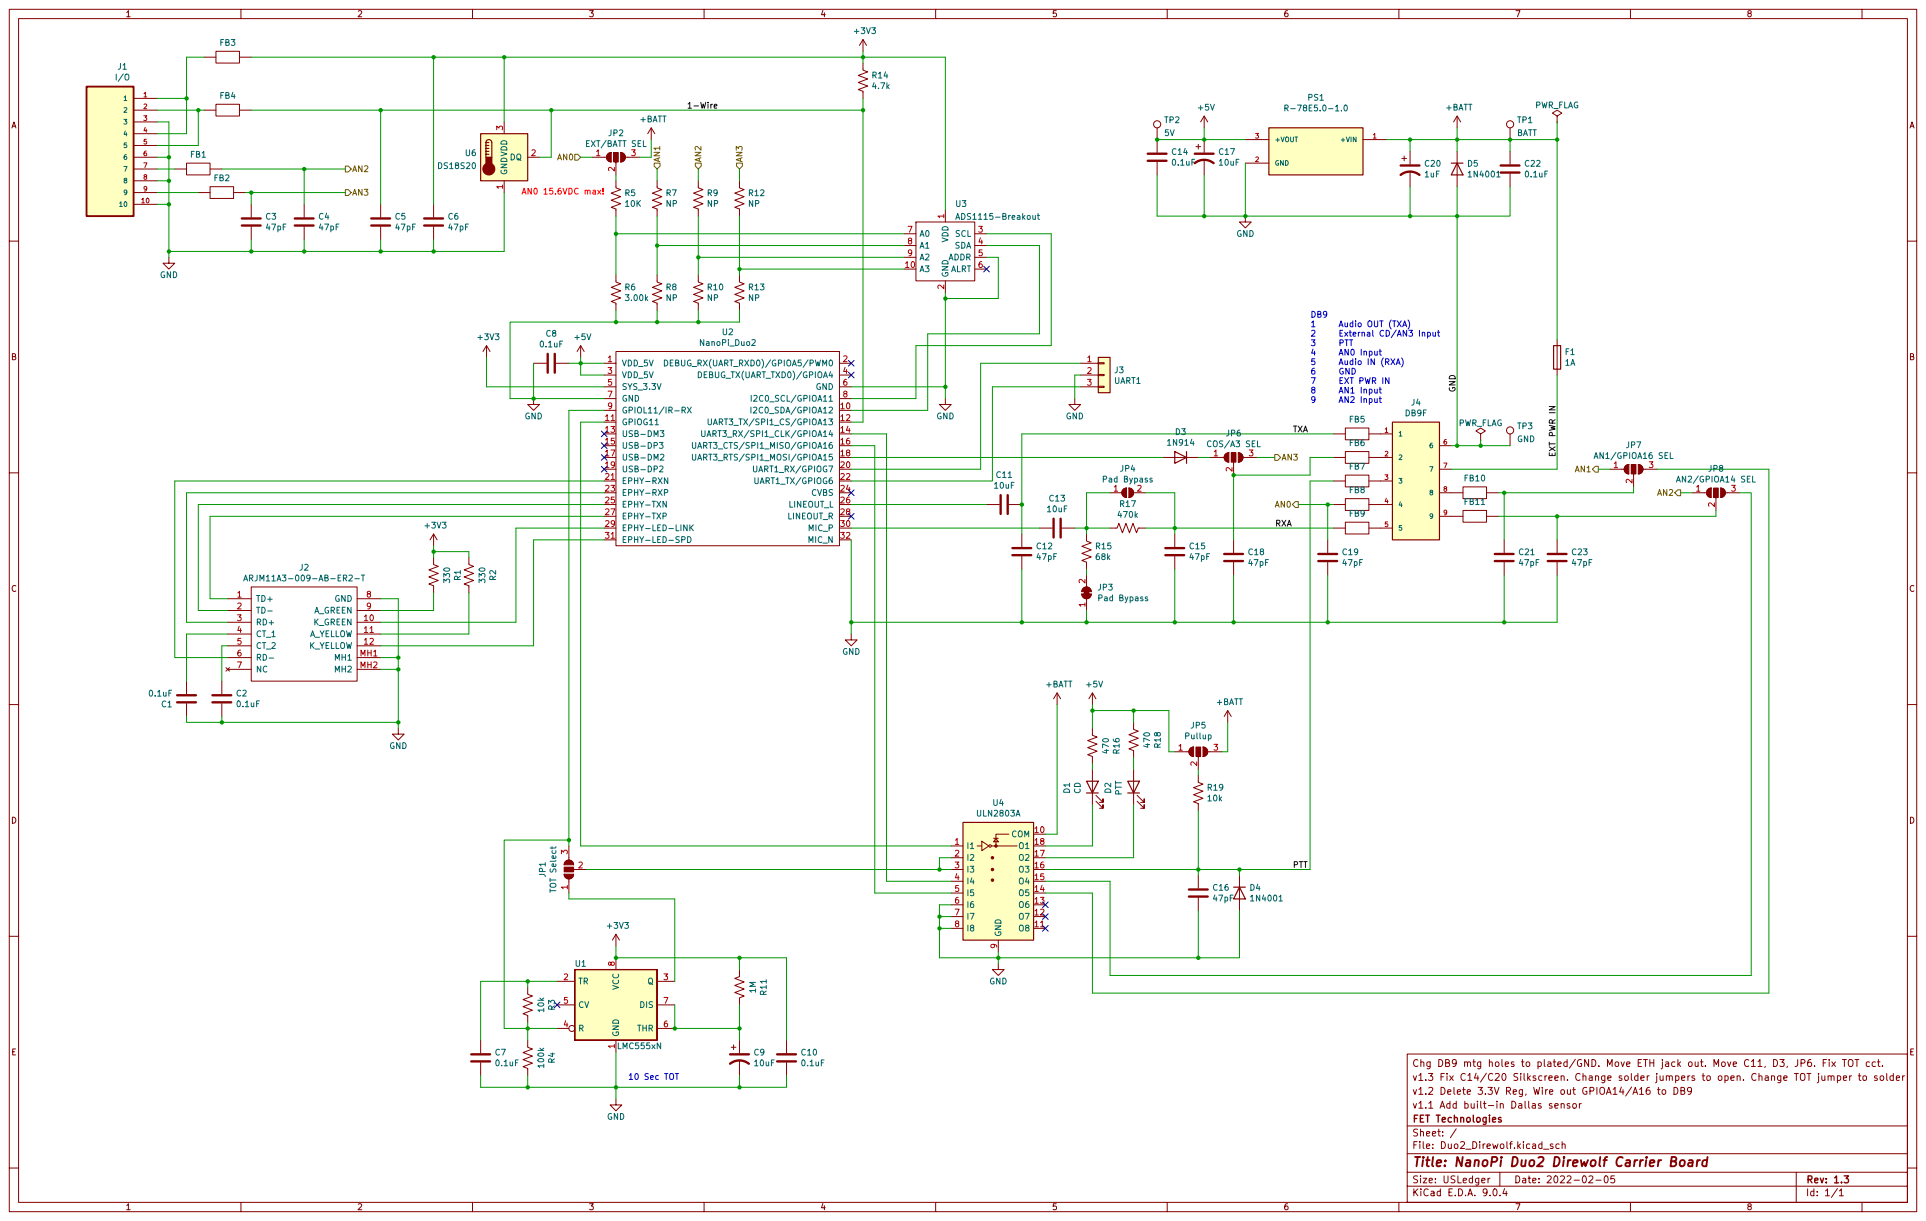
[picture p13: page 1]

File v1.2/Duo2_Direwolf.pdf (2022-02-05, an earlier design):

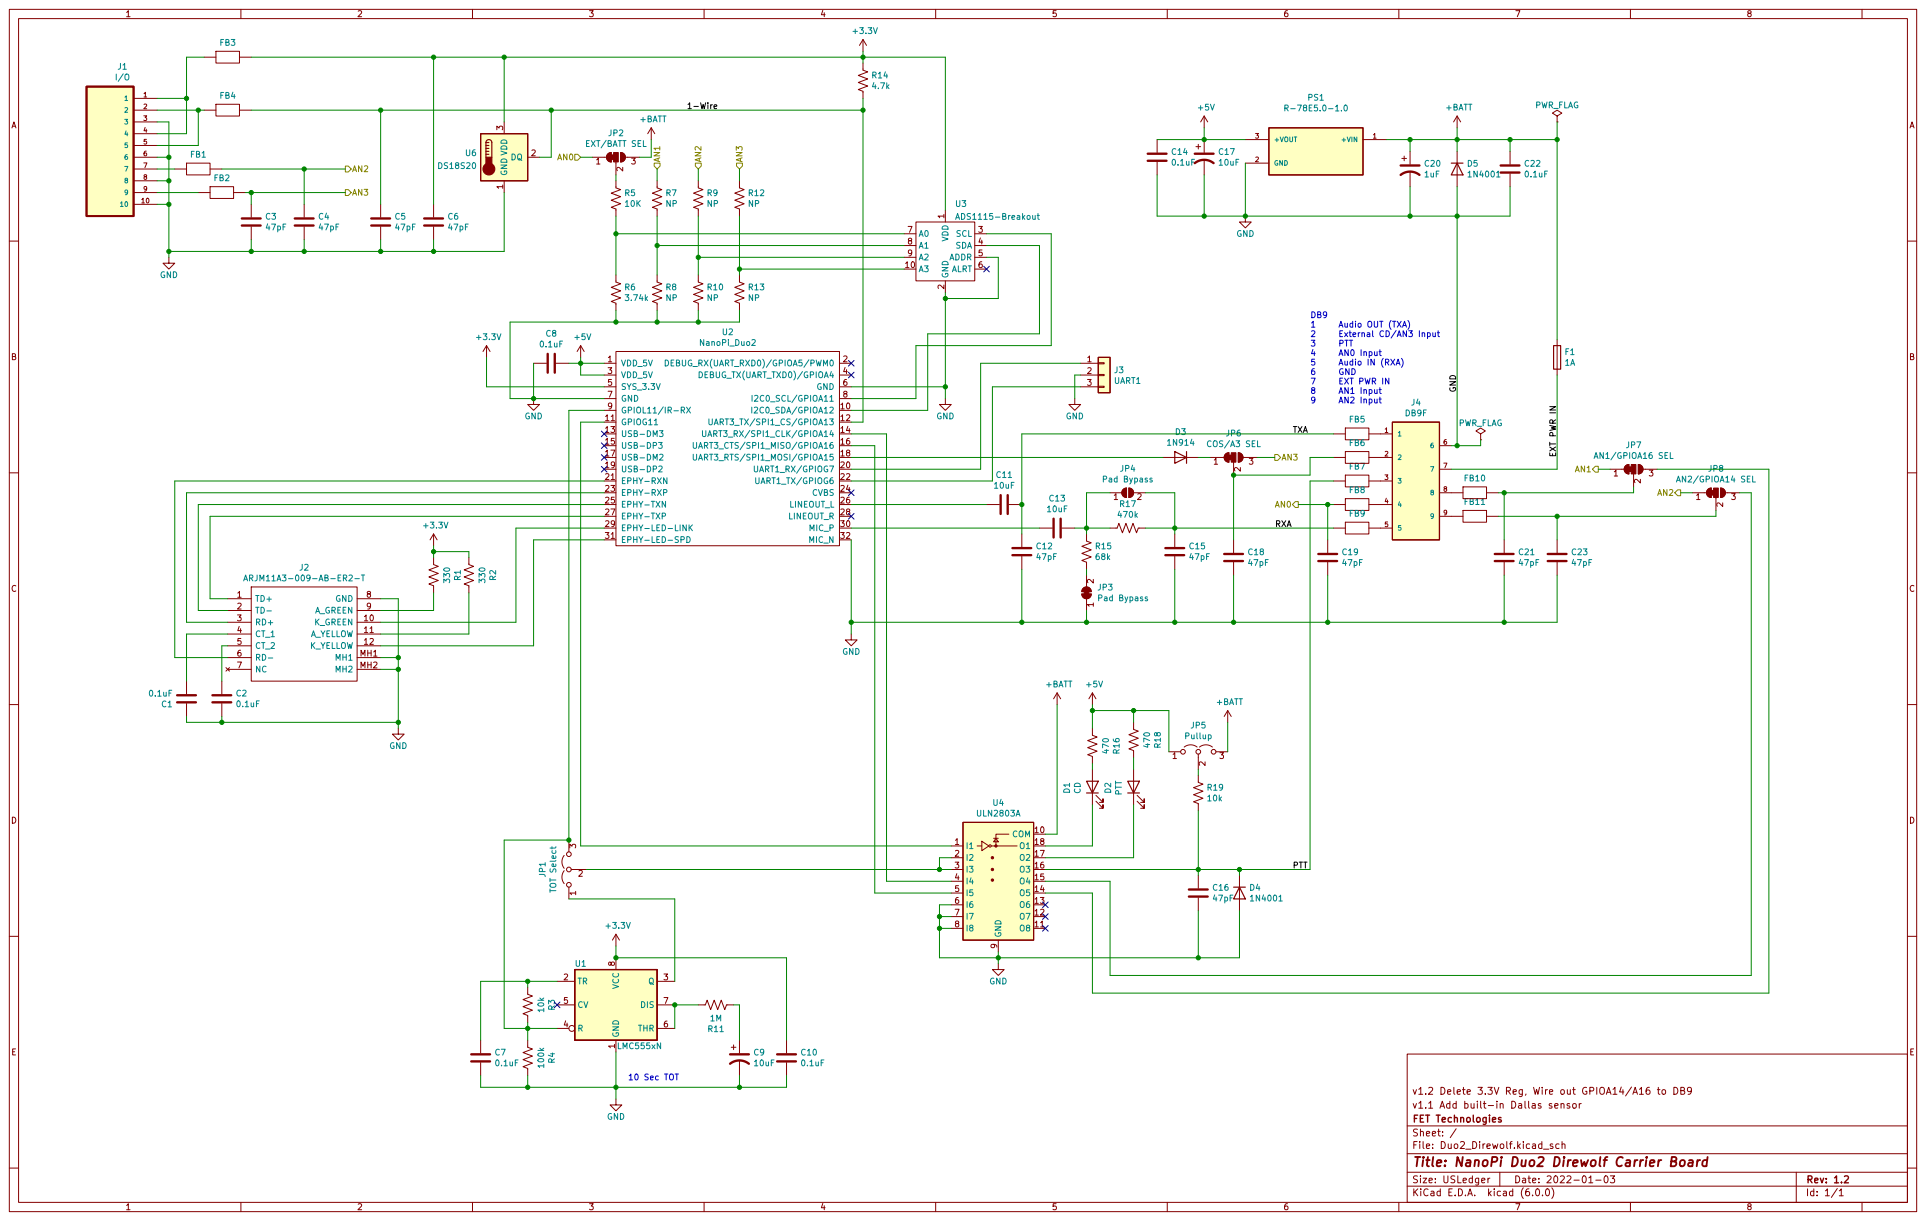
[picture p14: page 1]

2 SCL 3 SDA 4 ADDR 5 ALRT 6 A0 7 A1 8 A2 9 U3ADS1115-Breakout GND GND

1 Audio OUT (TXA)
2 External CD/AN3 Input 3 PTT

4 AN0 Input
5 Audio IN (RXA) 6 GND

v1.1 Add built-in Dallas sensor v1.2 Delete 3.3V Reg, Wire out GPIOA14/A16 to DB9

File: Duo2_Direwolf.kicad_sch Sheet: / FET Technologies

Id: 1/1 Title: NanoPi Duo2 Direwolf Carrier Board

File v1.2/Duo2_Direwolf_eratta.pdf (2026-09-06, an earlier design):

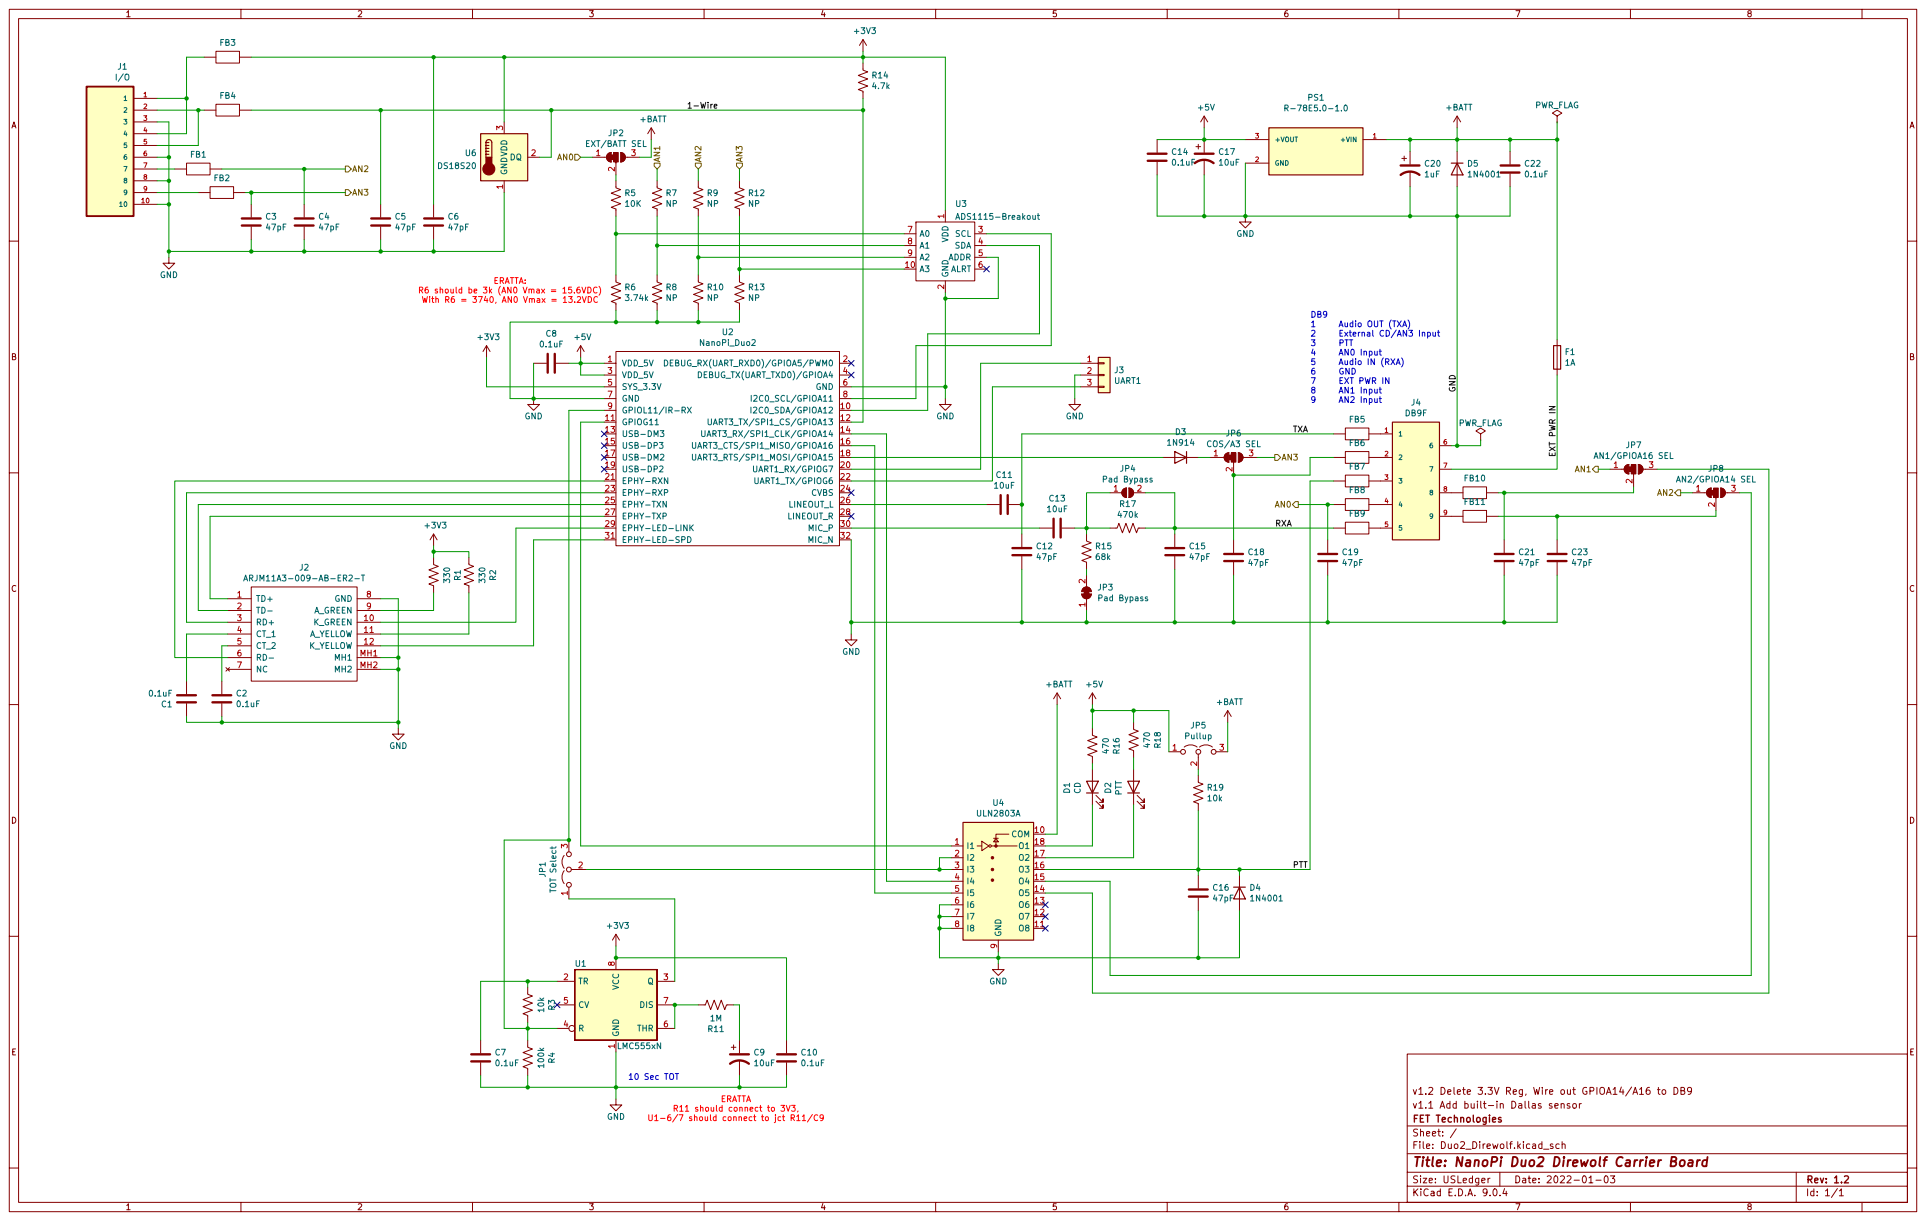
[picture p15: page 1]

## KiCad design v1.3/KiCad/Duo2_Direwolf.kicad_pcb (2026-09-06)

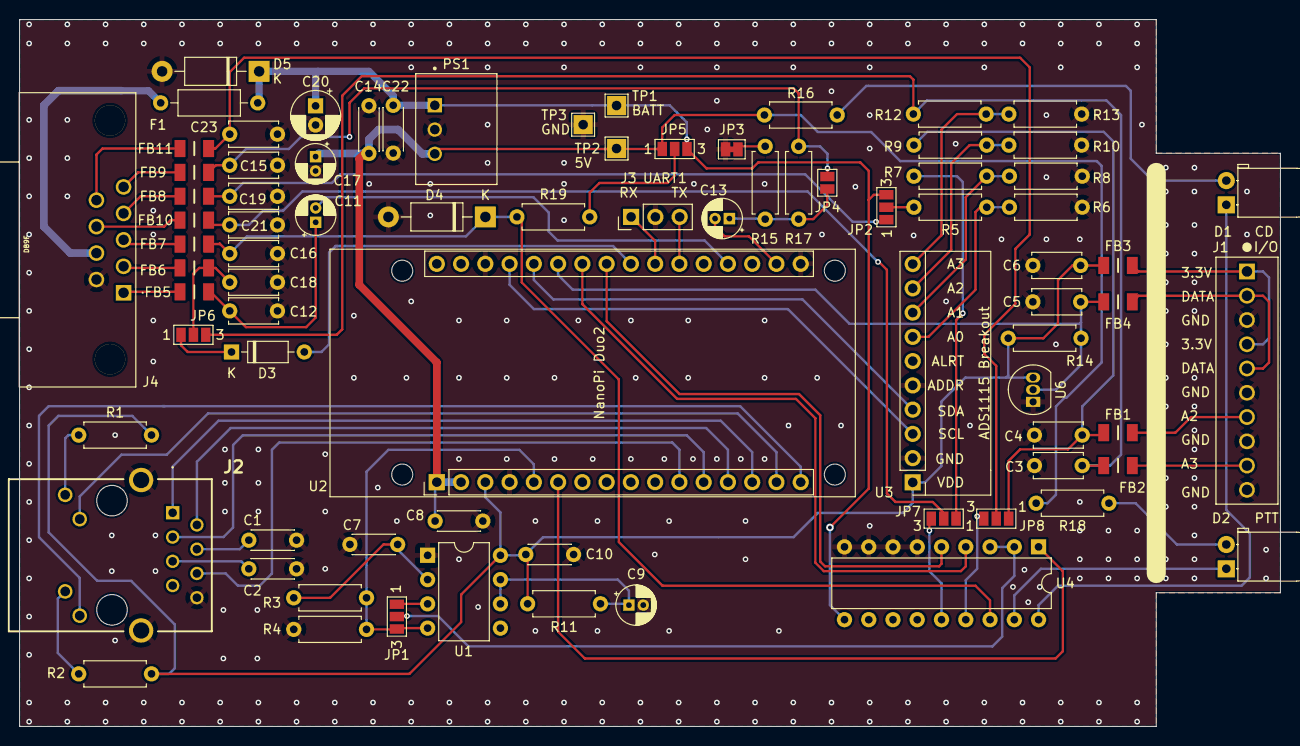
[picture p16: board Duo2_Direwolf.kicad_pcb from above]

Board: 2 copper layers, 132.0 x 74.0 mm, 80 parts (0 on the bottom side), 67 nets.

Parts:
C1, C2, C7, C8, C10, C14, C22: 0.1uF; C_Disc_D4.3mm_W1.9mm_P5.00mm
C3, C4, C5, C6, C12, C15, C16, C18, C19, C21, C23: 47pF; C_Disc_D5.0mm_W2.5mm_P5.00mm
C9, C11, C13, C17: 10uF; CP_Radial_D4.0mm_P1.50mm
C20: 1uF; CP_Radial_D5.0mm_P2.00mm
D1: CD; LED_D5.0mm_Horizontal_O1.27mm_Z3.0mm
D2: PTT; LED_D5.0mm_Horizontal_O1.27mm_Z3.0mm
D3: 1N914; D_DO-35_SOD27_P7.62mm_Horizontal
D4, D5: 1N4001; D_DO-41_SOD81_P10.16mm_Horizontal
F1: 1A; R_Axial_DIN0207_L6.3mm_D2.5mm_P10.16mm_Horizontal
FB1, FB2, FB3, FB4, FB5, FB6, FB7, FB8, FB9, FB10, FB11: MH3261-601Y; BEADC3216X130N
J1: I/O; TE_1-282834-0
J2: ARJM11A3-009-AB-ER2-T; ARJM11A3009ABER2T
J3: UART1; PinHeader_1x03_P2.54mm_Vertical
J4: DB9F; TE_2311765-1
JP1: TOT Select; SolderJumper-3_P1.3mm_Open_Pad1.0x1.5mm_NumberLabels
JP2: EXT/BATT SEL; SolderJumper-3_P1.3mm_Open_Pad1.0x1.5mm_NumberLabels
JP3: Pad Bypass; SolderJumper-2_P1.3mm_Bridged_Pad1.0x1.5mm
JP4: Pad Bypass; SolderJumper-2_P1.3mm_Open_Pad1.0x1.5mm
JP5: Pullup; SolderJumper-3_P1.3mm_Open_Pad1.0x1.5mm_NumberLabels
JP6: COS/A3 SEL; SolderJumper-3_P1.3mm_Open_Pad1.0x1.5mm_NumberLabels
JP7: AN1/GPIOA16 SEL; SolderJumper-3_P1.3mm_Open_Pad1.0x1.5mm_NumberLabels
JP8: AN2/GPIOA14 SEL; SolderJumper-3_P1.3mm_Open_Pad1.0x1.5mm_NumberLabels
PS1: R-78E5.0-1.0; CONV_R-78E5.0-1.0
R1, R2: 330; R_Axial_DIN0207_L6.3mm_D2.5mm_P7.62mm_Horizontal
R3, R19: 10k; R_Axial_DIN0207_L6.3mm_D2.5mm_P7.62mm_Horizontal
R4: 100k; R_Axial_DIN0207_L6.3mm_D2.5mm_P7.62mm_Horizontal
R5: 10K; R_Axial_DIN0207_L6.3mm_D2.5mm_P7.62mm_Horizontal
R6: 3.00k; R_Axial_DIN0207_L6.3mm_D2.5mm_P7.62mm_Horizontal
R7, R8, R9, R10, R12, R13: NP; R_Axial_DIN0207_L6.3mm_D2.5mm_P7.62mm_Horizontal
R11: 1M; R_Axial_DIN0207_L6.3mm_D2.5mm_P7.62mm_Horizontal
R14: 4.7k; R_Axial_DIN0207_L6.3mm_D2.5mm_P7.62mm_Horizontal
R15: 68k; R_Axial_DIN0207_L6.3mm_D2.5mm_P7.62mm_Horizontal
R16, R18: 470; R_Axial_DIN0207_L6.3mm_D2.5mm_P7.62mm_Horizontal
R17: 470k; R_Axial_DIN0207_L6.3mm_D2.5mm_P7.62mm_Horizontal
TP1: BATT; TestPoint_THTPad_2.0x2.0mm_Drill1.0mm
TP2: 5V; TestPoint_THTPad_2.0x2.0mm_Drill1.0mm
TP3: GND; TestPoint_THTPad_2.0x2.0mm_Drill1.0mm
U1: LMC555xN; DIP-8_W7.62mm
U2: NanoPi_Duo2; NanoPi_Duo2_Foot
U3: ADS1115-Breakout; ADS1115 Breakout
U4: ULN2803A; DIP-18_W7.62mm
U6: DS18S20; TO-92_Inline

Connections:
+3V3: C6.1, C10.1, FB3.2, R1.2, R2.2, R11.1, R14.2, U1.8 (VCC), U2.5 (SYS_3.3V), U3.1 (VDD), U6.3 (VDD)
+5V: C8.1, C14.1, C17.1, JP5.1 (A), PS1.3 (+VOUT), R16.2, R18.2, TP2.1, U2.1 (VDD_5V), U2.3 (VDD_5V)
+BATT: C20.1, C22.1, D5.1 (K), F1.1, JP2.3 (B), JP5.3 (B), PS1.1 (+VIN), TP1.1, U4.10 (COM)
/1-Wire: C5.1, FB4.2, R14.1, U2.12 (UART3_TX/SPI1_CS/GPIOA13), U6.2 (DQ)
/AN0: C19.1, FB8.1, JP2.1 (A)
/AN1: JP7.1 (A), R7.2
/AN2: C4.1, FB1.2, JP8.1 (A), R9.2
/AN3: C3.1, FB2.2, JP6.3 (B), R12.2
/EXT PWR IN: F1.2, J4.7
/PTT: C16.1, D4.1 (K), FB7.1, R19.1, U4.16 (O3)
/RXA: C15.1, FB9.1, JP4.2 (B), R17.1
/TXA: C11.1, C12.1, FB5.1
GND: C1.1, C2.2, C3.2, C4.2, C5.2, C6.2, C7.2, C8.2, C9.2, C10.2, C12.2, C14.2, C15.2, C16.2, C17.2, C18.2, C19.2, C20.2, C21.2, C22.2, C23.2, D4.2 (A), D5.2 (A), J1.3, J1.6, J1.8, J1.10, J2.8 (GND), J2.MH1, J2.MH2, J3.2, J4.6, JP3.1 (A), PS1.2 (GND), R4.1, R6.1, R8.1, R10.1, R13.1, TP3.1, U1.1 (GND), U2.6 (GND), U2.7 (GND), U2.32 (MIC_N), U3.2 (GND), U3.5 (ADDR), U4.6 (I6), U4.7 (I7), U4.8 (I8), U4.9 (GND), U6.1 (GND)
unnamed: D1.2 (A), R16.1
unnamed: D1.1 (K), U4.18 (O1)
unnamed: D2.2 (A), R18.1
unnamed: D2.1 (K), U4.17 (O2)
unnamed: D3.2 (A), U2.18 (UART3_RTS/SPI1_MOSI/GPIOA15)
unnamed: D3.1 (K), JP6.1 (A)
unnamed: FB1.1, J1.7
unnamed: FB2.1, J1.9
unnamed: FB3.1, J1.1, J1.4
unnamed: FB4.1, J1.2, J1.5
unnamed: FB5.2, J4.1
unnamed: FB6.2, J4.2
unnamed: FB7.2, J4.3
unnamed: FB8.2, J4.4
unnamed: FB9.2, J4.5
unnamed: FB10.1, J4.8
unnamed: FB11.1, J4.9
unnamed: J2.9 (A_GREEN), R1.1
unnamed: J2.11 (A_YELLOW), R2.1
unnamed: C1.2, J2.4 (CT_1)
unnamed: C2.1, J2.5 (CT_2)
unnamed: J2.10 (K_GREEN), U2.29 (EPHY-LED-LINK)
unnamed: J2.12 (K_YELLOW), U2.31 (EPHY-LED-SPD)
unnamed: J2.3 (RD+), U2.23 (EPHY-RXP)
unnamed: J2.6 (RD-), U2.21 (EPHY-RXN)
unnamed: J2.1 (TD+), U2.27 (EPHY-TXP)
unnamed: J2.2 (TD-), U2.25 (EPHY-TXN)
unnamed: J3.1, U2.20 (UART1_RX/GPIOG7)
unnamed: J3.3, U2.22 (UART1_TX/GPIOG6)
unnamed: JP1.1 (A), U1.3 (Q)
unnamed: JP1.3 (B), R3.1, R4.2, U1.4 (R), U2.9 (GPIOL11/IR-RX)
unnamed: JP1.2 (C), U4.2 (I2), U4.3 (I3)
unnamed: JP2.2 (C), R5.2
unnamed: JP3.2 (B), R15.1
unnamed: C13.1, JP4.1 (A), R15.2, R17.2
unnamed: JP5.2 (C), R19.2
unnamed: C18.1, FB6.1, JP6.2 (C)
unnamed: JP7.3 (B), U4.14 (O5)
unnamed: C21.1, FB10.2, JP7.2 (C)
unnamed: JP8.3 (B), U4.15 (O4)
unnamed: C23.1, FB11.2, JP8.2 (C)
unnamed: C9.1, R11.2, U1.6 (THR), U1.7 (DIS)
unnamed: C7.1, R3.2, U1.2 (TR)
unnamed: U2.11 (GPIOG11), U4.1 (I1)
unnamed: U2.8 (I2C0_SCL/GPIOA11), U3.3 (SCL)
unnamed: U2.10 (I2C0_SDA/GPIOA12), U3.4 (SDA)
unnamed: C11.2, U2.26 (LINEOUT_L)
unnamed: C13.2, U2.30 (MIC_P)
unnamed: U2.16 (UART3_CTS/SPI1_MISO/GPIOA16), U4.5 (I5)
unnamed: U2.14 (UART3_RX/SPI1_CLK/GPIOA14), U4.4 (I4)
unnamed: R5.1, R6.2, U3.7 (A0)
unnamed: R7.1, R8.2, U3.8 (A1)
unnamed: R9.1, R10.2, U3.9 (A2)
unnamed: R12.1, R13.2, U3.10 (A3)

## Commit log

2022-02-05 Upload v1.2 files.
    [Duo2_Direwolf-B_Cu.gbr, Duo2_Direwolf-B_Mask.gbr, Duo2_Direwolf-B_Paste.gbr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]
2022-02-05 Add BOM.
2022-02-06 Add v1.3 files.
    [Duo2_Direwolf.kicad_pcb, Duo2_Direwolf.kicad_sch]
2022-02-06 Add v1.3 Gerbers.
    [Duo2_Direwolf-B_Cu.gbr, Duo2_Direwolf-B_Mask.gbr, Duo2_Direwolf-B_Paste.gbr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]
2022-02-06 Update suitable enclosures.
2026-09-06 Update with as-built changes and errata to v1.2. Changes updated in v1.3 for future production.
    [Duo2_Direwolf-B_Cu.gbr, Duo2_Direwolf-B_Mask.gbr, Duo2_Direwolf-B_Paste.gbr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]
2026-09-06 Add files for 3D printing an enclosure.
    [WolfPiBox_v1.2_121mmdeep-BotLid.stl, WolfPiBox_v1.2_121mmdeep-TopLid.stl, WolfPiBox_v1.2_121mmdeep-WolfPiCase.stl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]
